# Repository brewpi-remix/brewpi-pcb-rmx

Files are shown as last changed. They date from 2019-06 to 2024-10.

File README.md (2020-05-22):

# BrewPi Remix Logo

*[@LBussy](https://github.com/lbussy)'s forks of the original [BrewPi Project](https://github.com/BrewPi)*.  This project has a new website, please also visit https://www.brewpiremix.com.  All files will remain here, the website is just to make it easier for me to keep current information available.

# BrewPi Remix Printed Circuit Board Eagle Files

This repository contains the Eagle files for printed circuit boards supporting [BrewPi Remix](https://www.brewpi.com/this-is-brewpi-0-2/).

## Boards Provided
Within this repository are:

- ESP8266 Boards (Supporting @Thorrak's [ESP8266 BrewPi Controllers](https://github.com/thorrak/brewpi-esp8266))
  - Wemos D1 breakout supporting BrewPi Remix or Fermentrack using @Thorrak's [ESP8266 firmware](https://github.com/thorrak/brewpi-esp8266)
  - RJ-45 breakout board, supporting ESP8266 controllers connected via straight-throgh RJ-45 (i,e, Ethernet) cables
- Arduino Uno shield supporting BrewPi Remix RevC as well as I2C
  - Rotary Encoder breakout to facilitate connecting a rotary encoder with DuPont wires
  - Breakout board, mostly for bench work, providing all possible connections via screw terminals as well as DuPont connections, plus heat/cool LED indicators

## Boards Manufacture
You may order boards for manufacture directly from these links:
- Arduino Shield [From PCBs.io](https://PCBs.io/share/zdeBw)
- Wemos D1 breakout [From PCBs.io](https://PCBs.io/share/z5JLZ)
- Breakout Board [From PCBs.io](https://PCBs.io/share/zvpLA)
- Rotary Encoder Breakout Board [From PCBs.io](https://PCBs.io/share/rJPlG)

## Modifying These Files
If you would like to personalize these board designs, you may modify them with [Autodesk's EAGLE](https://www.autodesk.com/products/eagle/overview). EAGLE is a scriptable electronic design automation (EDA) application with schematic capture, printed circuit board (PCB) layout, auto-router and computer-aided manufacturing (CAM) features. EAGLE stands for Easily Applicable Graphical Layout Editor and is developed by CadSoft Computer GmbH. The company was acquired by Autodesk Inc. in 2016.  

The program supports Windows, Linux, and Mac OS X.  EAGLE is available in a [free version](https://www.autodesk.com/products/eagle/free-download), as well as a [subscription-based version with more features](https://www.autodesk.com/products/eagle/compare).

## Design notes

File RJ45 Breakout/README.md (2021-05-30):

# BrewPi Remix Logo

Make or buy?  That is the question.  Since providing the below listed DIY breakout, I found these on Amazon (of course!):

- [Four-Way RJ45 Breakout Board](https://smile.amazon.com/Electronics-Salon-4-Way-Breakout-Terminal-Connector/dp/B01GNOBDPM)
- [RJ45 Ethernet Splitter (2-way)](https://smile.amazon.com/Splitter-Connectors-Ethernet-Interface-Internet/dp/B07CW7JHYV)
- [RJ45 Ethernet Splitter (3-way)](https://smile.amazon.com/Ethernet-Splitter-vienon-Adapter-Connector/dp/B0932B8JGJ)

I have the below setup in all my fermenters, but I have to say I might be tempted to use these if I had to do it again.

Note: These links are NOT affiliat elinks but are pointing to [smile.amazon.com](https://smile.amazon.com/gp/chpf/about/).  If you are not currently enrolled in this program, you should at least review the link.  It's an easy way to support your favorite charity every time you shop on Amazon.  If you are at a loss to pick a charity, may I suggest the [Wounded Warrior Project](https://www.woundedwarriorproject.org/)?

If you are interested in building a splitter, here's one way to go:

# RJ-45 Sensor Breakout

A breakout board created to connect sensors and the door switch via an RJ-45 straight-through cable (i.e. Ethernet.)

[Order from PCBs.io](#):

- 2 Layer Board - 0.7087 sq in (0.7038in x 1.0069in) / 457.22 sq/mm (17.88mm x 25.58mm)
- $2.83 per set of 4 ($4.00 per sq in)

| Top View | Bottom View |
| --- |:---:|
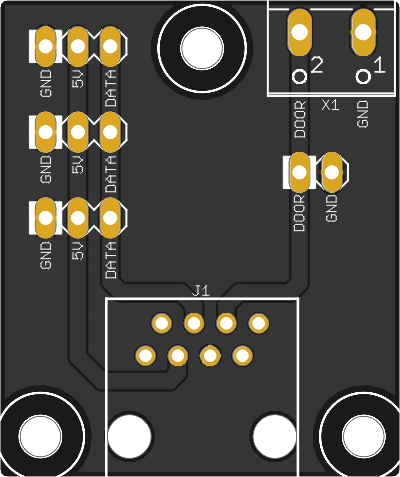
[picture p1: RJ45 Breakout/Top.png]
Board Top
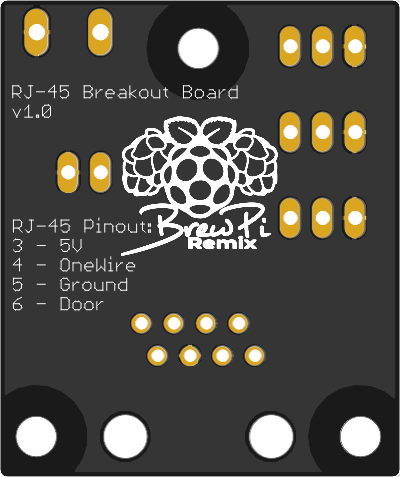
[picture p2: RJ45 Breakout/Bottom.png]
Board Bottom
|  |  |

[top]: Top.png "Board Top"
[bot]: Bottom.png "Board Bottom"

BOM:

- 1 x [PCB Breakout](#) (this project)
- 1 x [Wago 2-terminal Screw Clamp](https://www.aliexpress.com/item/32700056337.html) (X1)
- 3 x [Wago 3-terminal Screw Clamp](#) (X1)
- 1 x [RJ45 Modular Jack w/no shield](https://www.aliexpress.com/item/32736146888.html) (J1)

## Board Manufacture

You may order this board for manufacture directly from [PCBs.io](https://PCBs.io/share/rJPlG).

## 3D-Printed Case

See [this case](#) from Thorrak for a case you can print.

## Modifying These Files

If you would like to personalize these board designs, you may modify them with [Autodesk's EAGLE](https://www.autodesk.com/products/eagle/overview). EAGLE is a scriptable electronic design automation (EDA) application with schematic capture, printed circuit board (PCB) layout, auto-router and computer-aided manufacturing (CAM) features. EAGLE stands for Easily Applicable Graphical Layout Editor and is developed by CadSoft Computer GmbH. The company was acquired by Autodesk Inc. in 2016.  

The program supports Windows, Linux, and Mac OS X.  EAGLE is available in a [free version](https://www.autodesk.com/products/eagle/free-download), as well as a [subscription-based version with more features](https://www.autodesk.com/products/eagle/compare).

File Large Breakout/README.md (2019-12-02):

# BrewPi Remix Logo

# BrewPi Breakout v1.3.1a

Breakout Board for the [BrewPi Legacy Remix](https://www.brewpiremix.com) project. This optional breakout board is intended to be connected to the Arduino Shield v1.3.1a via a straight-through RJ45 terminated cable (i.e. an Ethernet cable.)  It allows the Arduino to be located remotely from the fermentation chamber.

[Order from PCBs.io](https://PCBs.io/share/zvpLA):

- 2 Layer Board - 2.3751 sq in (1.2130in x 1.9580in) / 1532.32 sq/mm (30.81mm x 49.73mm)
- $9.38 per set of 4 ($3.95 per sq in)

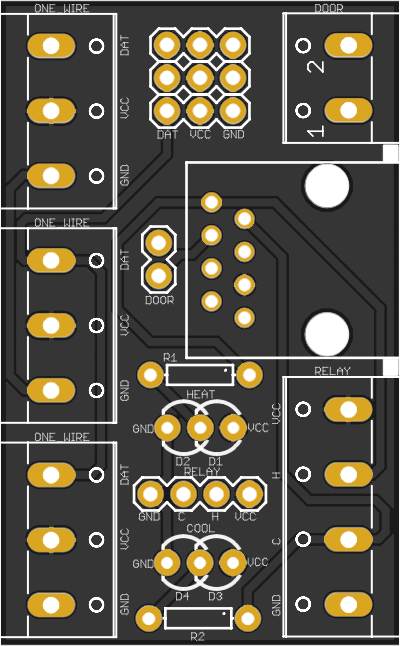
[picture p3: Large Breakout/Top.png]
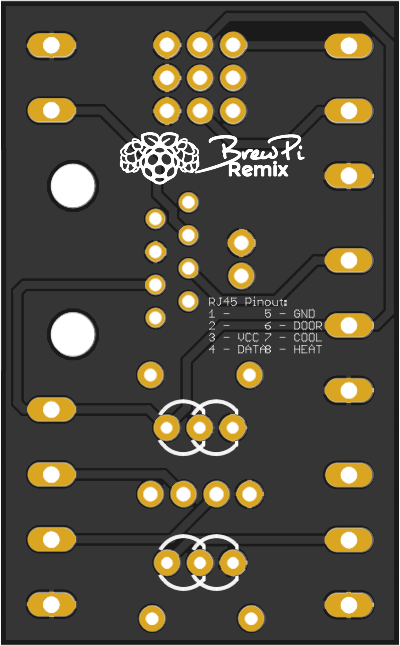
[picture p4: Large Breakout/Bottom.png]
 

## Supported Features:

  * Door switch
  * Heat/Cool
    * Dupont pins
    * Screw terminal
  * Heat/Cool LEDs
  * Temp Sensors
    * Three Dupont pin sets
    * Three screw terminals

## Usage Notes:
Since this board is intended to support multiple configurations, some customization during assembly is required.

  - Heat / Cool LEDs - You will use different connections for LEDs depending on the configuration of your actuators.  Connections are provided for two LEDs each for heat and cool, however you will only use one based on your setup
    - Inverted (typical for relay board) - Connect the LED between VCC and the center pin.  A resistor is not needed as there is one on the board
    - Non-Inverted (typical for SSRs) - Connect the LED between the center pin and GND.  A resistor is not needed as there is one on the board

## BOM:

  * 1 ea [Red 3mm LED](https://www.mouser.com/ProductDetail/638-MV5064.MP4B)
  * 1 ea [Blue 3mm LED](https://www.mouser.com/ProductDetail/941-C503BBCNCV0Z0461)
  * 2 ea [220Ω 1/4W Axial Resistors](https://www.mouser.com/ProductDetail/660-MF1-4DCT52R2200F)
  * 1 ea 4-Pin header
  * 1 ea 2-Pin header
  * 3 ea 3-Pin headers
  * 1 ea RJ45 terminal
  * 3 ea 3-Position screw terminal
  * 1 ea 4-Position screw terminal
  * 1 ea 2-Position screw terminal

## Board Manufacture
You may order this board for manufacture directly from [PCBs.io](https://PCBs.io/share/zvpLA).

## Modifying These Files
If you would like to personalize these board designs, you may modify them with [Autodesk's EAGLE](https://www.autodesk.com/products/eagle/overview). EAGLE is a scriptable electronic design automation (EDA) application with schematic capture, printed circuit board (PCB) layout, auto-router and computer-aided manufacturing (CAM) features. EAGLE stands for Easily Applicable Graphical Layout Editor and is developed by CadSoft Computer GmbH. The company was acquired by Autodesk Inc. in 2016.  

The program supports Windows, Linux, and Mac OS X.  EAGLE is available in a [free version](https://www.autodesk.com/products/eagle/free-download), as well as a [subscription-based version with more features](https://www.autodesk.com/products/eagle/compare).

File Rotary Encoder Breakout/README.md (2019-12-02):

# BrewPi Remix Logo

# Rotary Encoder Breakout v1.0

A breakout board to provide pins for connecting the rotary encoder to the BrewPi controller.  Designed for CUI, [ACZ11BR1E-15FD1-20C](https://www.mouser.com/ProductDetail/490-CZ11BR1E15FD120C) or similar footprint.  Despite the picture linked on that page, you want a vertical mounting encoder (and that one really is.)  You don't really *need* this, but it will surely make it easier to connect things with Dupont wires.

[Order from PCBs.io](https://PCBs.io/share/rJPlG):

- 2 Layer Board - 0.7087 sq in (0.7038in x 1.0069in) / 457.22 sq/mm (17.88mm x 25.58mm)
- $2.83 per set of 4 ($4.00 per sq in)

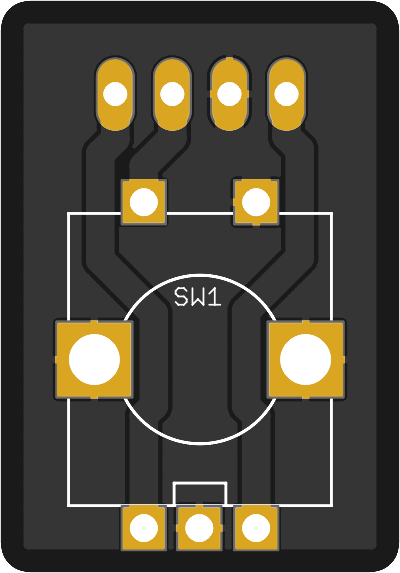
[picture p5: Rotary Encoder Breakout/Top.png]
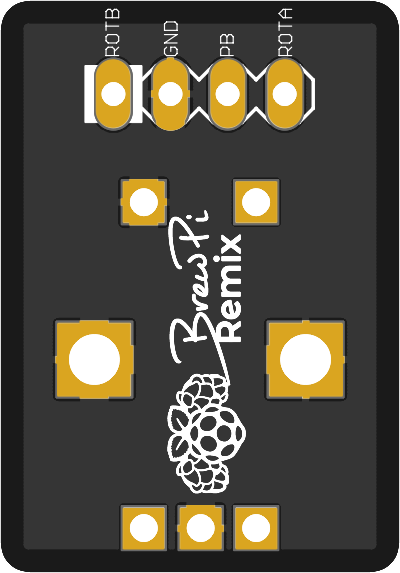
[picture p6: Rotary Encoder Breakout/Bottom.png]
 

## BOM:

- 1 each [PCB](https://PCBs.io/share/rJPlG) (this project)
- 1 each [Four-pin 2.54mm Dupont header](https://www.mouser.com/ProductDetail/3M-Electronic-Solutions-Division/2306-6111-TG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), male or female according to your preference
- 1 each CUI [Rotary Encoder ACZ11BR1E-15FD1-20C](https://www.mouser.com/ProductDetail/490-CZ11BR1E15FD120C)  You want a magnetic encoder with a vertical shaft, no pull-ups, and 20 detents
- 1 each [Rotary Knob](https://www.mouser.com/ProductDetail/450-4763)

## Board Manufacture

You may order this board for manufacture directly from [PCBs.io](https://PCBs.io/share/rJPlG).

## Modifying These Files

If you would like to personalize these board designs, you may modify them with [Autodesk's EAGLE](https://www.autodesk.com/products/eagle/overview). EAGLE is a scriptable electronic design automation (EDA) application with schematic capture, printed circuit board (PCB) layout, auto-router and computer-aided manufacturing (CAM) features. EAGLE stands for Easily Applicable Graphical Layout Editor and is developed by CadSoft Computer GmbH. The company was acquired by Autodesk Inc. in 2016.  

The program supports Windows, Linux, and Mac OS X.  EAGLE is available in a [free version](https://www.autodesk.com/products/eagle/free-download), as well as a [subscription-based version with more features](https://www.autodesk.com/products/eagle/compare).

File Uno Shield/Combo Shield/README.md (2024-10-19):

# BrewPi Remix Logo

# BrewPi Arduino Uno Shield v1.3.1a (I2C/Parallel LCD)

Arduino Uno shield for the [BrewPi Remix](https://www.brewpiremix.com) project. This is an new board design which incorporates an I2C LCD header in addition to the original parallel LCD header on the RevC.  The I2C display is supported in version 0.5.3 of BrewPi Legacy Remix Scripts, WWW and Tools, coupled with version 0.2.12 of the Arduino Firmware.

[Order from PCBs.io]():  (I removed this link because PCBs.io appear to have been overtaken by malware.  [OshPark](https://oshpark.com/) is a good choice for smaller quantities.)

- 2 Layer Board - 5.1164 sq in (2.1200in x 2.4134in) / 3300.9 sq/mm (53.85mm x 61.3mm)
- $19.39 per set of 4 ($3.79 per sq in)

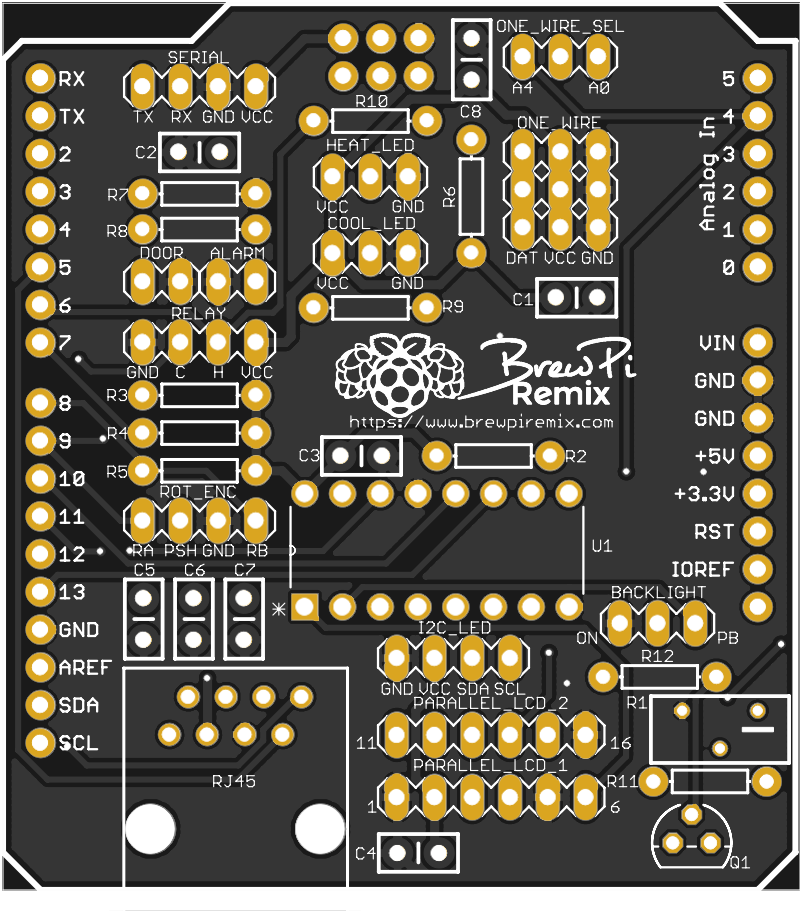
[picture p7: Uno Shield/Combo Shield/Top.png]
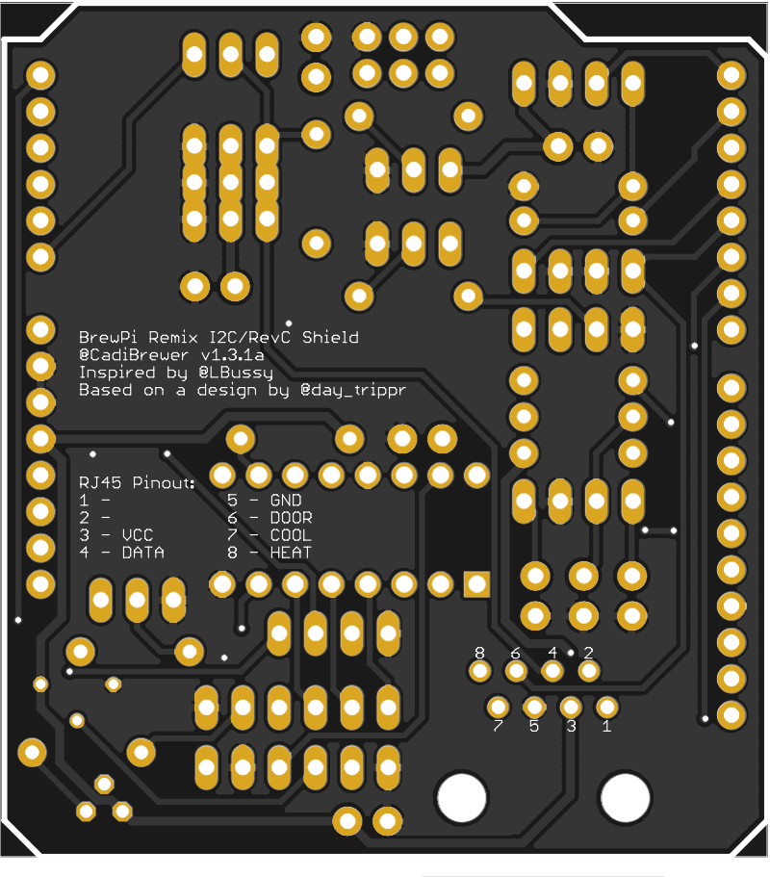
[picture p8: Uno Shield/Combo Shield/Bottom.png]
 

## Supported Features:

  * Wireless to Serial Bridge (Bluetooth or ESP8266 module)
  * Door switch
  * Alarm
  * Heat/Cool Relay
  * Rotary Encoder w/Pushbutton
  * Heat/Cool LEDs
  * OneWire Selector A0/A4 (required for I2C)
  * Three OneWire connections
  * I2C LCD; or;
  * Parallel LCD
  * RJ45 connector includes support for:
    * OneWire
    * Door Switch
    * Heat/Cool Relay
  * All Arduino headers available

## Usage Notes:
Since this board is intended to support both the RevC as well as the I2C firmware, some configuration is required via jumper caps.

  - ONE_WIRE_SEL Jumper - If you do not select the proper configuration, you may not be able to configure the OneWire sensors, the display may fault, or both.
    - Jump between A4 and the center pin for RevC
    - Jump between A0 and the center pin for I2C
  - Backlight Timeout - If you do not have a rotary encoder you will not be able to wake the backlight if it times out.  You can configure the board to never turn off the backlight
    - RevC - The BACKLIGHT jumper has two settings:
      - Jump between ON and the center pin to have the backlight stay on
      - Jump between PB and the center pin to have the backlight time out
    - I2C - The backlight setting uses the rotary encoder header
      - If you have a rotary encoder, pushing the button during a controller reset will disable backlight timer
      - If you do not have a rotary encoder, adding a jumper on the ROT_ENC header between PSH and GND will disable backlight timer
  - Heat / Cool LEDs - You will use different connections for LEDs depending on the configuration of your actuators
    - Inverted (typical for relay board) - Connect the LED between VCC and the center pin.  A resistor is not needed as there is one on the board
    - Non-Inverted (typical for SSRs) - Connect the LED between the center pin and GND.  A resistor is not needed as there is one on the board

## BOM:

  * From Mouser (by using [this link](https://www.mouser.com/ProjectManager/ProjectDetail.aspx?AccessID=d74098d8b5) you can view all of these parts on Mouser and simply click the "Order Project" button):
    * 7 ea [0.1μF Ceramic Capacitor](https://www.mouser.com/ProductDetail/?qs=PmkNt%2FFLxQc4kNUCHU6a6Q%3D%3D) (C1-7)
    * 1 ea [1.0μF Ceramic Capacitor](https://www.mouser.com/ProductDetail/?qs=AQlKX63v8RtdX%2FUKFBhcig%3D%3D) (C8)
    * 1 ea [10kΩ Trimmer Resistor](https://www.mouser.com/ProductDetail/?qs=V3Em1enZyNPGF2%252BnCaKTKw%3D%3D) (R1)
    * 4 ea [10kΩ Axial Resistor 1/4W](https://www.mouser.com/ProductDetail/?qs=AtFvwFU%2F1FmCMXRebRRiVA%3D%3D) (R3-5, 12)
    * 1 ea [150Ω Axial Resistor 1/4W](https://www.mouser.com/ProductDetail/?qs=7jyBjEprRBipjkz1NPmruA%3D%3D) (R11)
    * 1 ea [1kΩ Axial Resistor 1/4W](https://www.mouser.com/ProductDetail/?qs=ddCg%252BR5cWn2sqOoxwN8P1g%3D%3D) (R8)
    * 1 ea [20kΩ Axial Resistor 1/4W](https://www.mouser.com/ProductDetail/KOA-Speer/MF1-4CC2002F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) (R2)
    * 2 ea [220Ω Axial Resistor 1/4W](https://www.mouser.com/ProductDetail/?qs=KVzGhl%2FcVV1aGF8Vc%2F%252BvDg%3D%3D) (R9, 10)
    * 1 ea [2kΩ Axial Resistor 1/4W](https://www.mouser.com/ProductDetail/?qs=iPPgFPFs9PM72iUDc08rBg%3D%3D) (R7)
    * 1 ea [4.7kΩ Axial Resistor 1/4W](https://www.mouser.com/ProductDetail/?qs=WbbykRgge7o4TK6QsdXS5A%3D%3D) (R6)
    * 1 ea [2N3906 PNP Transistor](https://www.mouser.com/ProductDetail/?qs=iN0KuJO79Kbn9o7a2lB4uA%3D%3D) (Q1)
    * 1 ea [SN74HC595N 8-Bit Shift Register](https://www.mouser.com/ProductDetail/?qs=IEl3ej0IqwBTHkYa8XPoMQ%3D%3D) (U1)
    * 1 ea [16-pin IC Socket](https://www.mouser.com/ProductDetail/?qs=5aG0NVq1C4zi9nx%252BGroISQ%3D%3D) (U1)
  * From Adafruit:
    * [Shield stacking headers for Arduino](https://www.adafruit.com/product/85)
    * [Break-away 0.1" 36-pin strip male header - Black - 10 pack](https://www.adafruit.com/product/392), more than enough for:
      * 2 ea 2-pin Header 2.54mm pitch (or 1 ea 4 pin)
      * 7 ea 3-pin Header 2.54mm pitch
      * 4 ea 4-pin Header 2.54mm pitch
      * 2 ea 6-pin Header 2.54mm pitch
  * 2 ea [Jumper Cap](https://www.amazon.com/ZYAMY-2-54mm-Standard-Circuit-Connection/dp/B077957RN7) (or you can use a female/female Dupont jumpers but caps are definitely better looking)
  * 1 ea [RJ45 Socket](https://www.aliexpress.com/item/High-Quality-20pcs-RJ45-8P8C-Computer-Internet-Network-PCB-Jack-Socket-Black/32736146888.html)

Other items you may want in order to complete your project:

  * LCD Display, either;
    * [20x4 LCD Parallel](https://www.amazon.com/SunFounder-Serial-Module-Arduino-Mega2560/dp/B071W8SW9R), or;
    * [20x4 LCD I2C](https://www.amazon.com/SunFounder-Serial-Module-Arduino-Mega2560/dp/B01GPUMP9C)
  * [5v 2-Channel Relay Module](https://www.amazon.com/gp/product/B00TMFVVG6)
  * [Rotary Encoder](https://www.mouser.com/ProductDetail/490-CZ11BR1E15FD120C)  - You want a magnetic encoder, no pull-ups, and 20 detents
  * [Knob for Rotary Encoder](https://www.mouser.com/ProductDetail/Eagle-Plastic-Devices/450-4763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)
  * [Rotary Encoder Breakout Board](https://PCBs.io/share/zkPZ0)
  * At least two [DS18B20 Waterproof Temperature Sensors](https://www.amazon.com/gp/product/B01JKVRVNI)
  * Assorted [Dupont Jumper Wires](https://www.amazon.com/Multicolored-Breadboard-Dupont-Jumper-Wires/dp/B073X7P6N2) (male-male, male-female, female-female)

## Board Manufacture

You may order this board for manufacture directly from [pcbs.io](https://PCBs.io/share/zdeBw).

## 3D-Printed Case

See [this case](https://www.thingiverse.com/thing:3416312) from @gromitdj for a case you can print.

## Modifying These Files
If you would like to personalize these board designs, you may modify them with [Autodesk's EAGLE](https://www.autodesk.com/products/eagle/overview). EAGLE is a scriptable electronic design automation (EDA) application with schematic capture, printed circuit board (PCB) layout, auto-router and computer-aided manufacturing (CAM) features. EAGLE stands for Easily Applicable Graphical Layout Editor and is developed by CadSoft Computer GmbH. The company was acquired by Autodesk Inc. in 2016.  

The program supports Windows, Linux, and Mac OS X.  EAGLE is available in a [free version](https://www.autodesk.com/products/eagle/free-download), as well as a [subscription-based version with more features](https://www.autodesk.com/products/eagle/compare).

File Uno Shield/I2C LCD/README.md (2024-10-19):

# I2C Uno Shield

The design here is specific to the I2C variant only of the BrewPi firmware.

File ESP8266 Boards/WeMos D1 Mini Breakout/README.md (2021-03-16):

# BrewPi Remix Logo

# Wemos D1 Mini BrewPi Breakout

A Wemos D1 Mini breakout board for BrewPi-derivative ESP8266 projects. No third-party level shifter is required.  Through-hole components only for ease of assembly.

[Order from OshPark](https://oshpark.com/shared_projects/YLXZEzde):

- 2 layer board of 1.74 x 1.74 inches (44.2 x 44.1 mm) 
- $15.10 per set of 3

| Top View | Bottom View |
| --- |:---:|
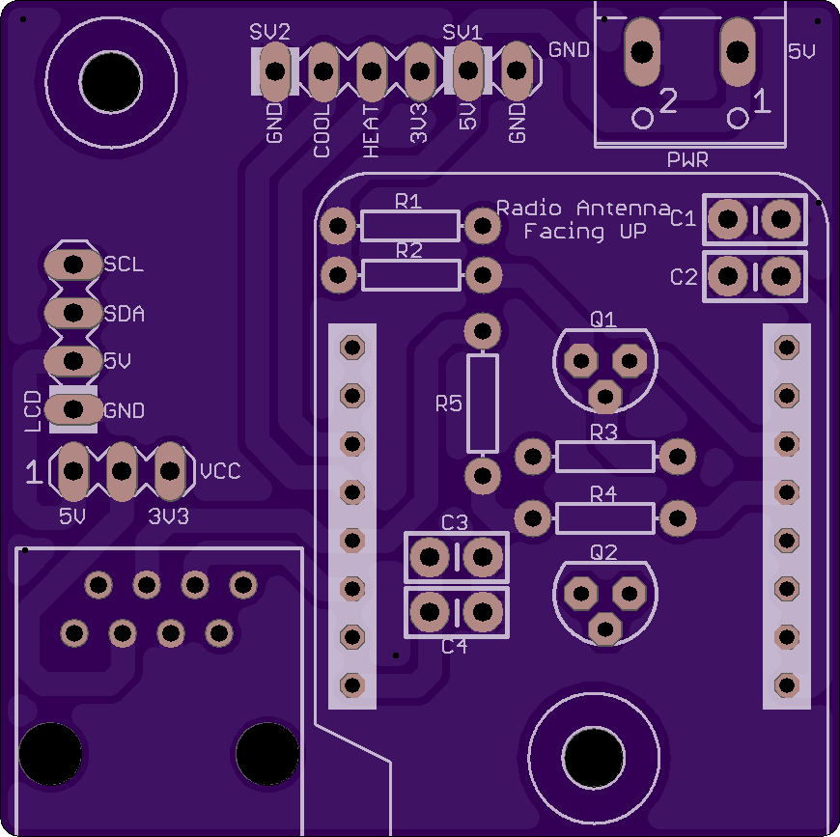
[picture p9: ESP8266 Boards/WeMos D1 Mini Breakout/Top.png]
Board Top
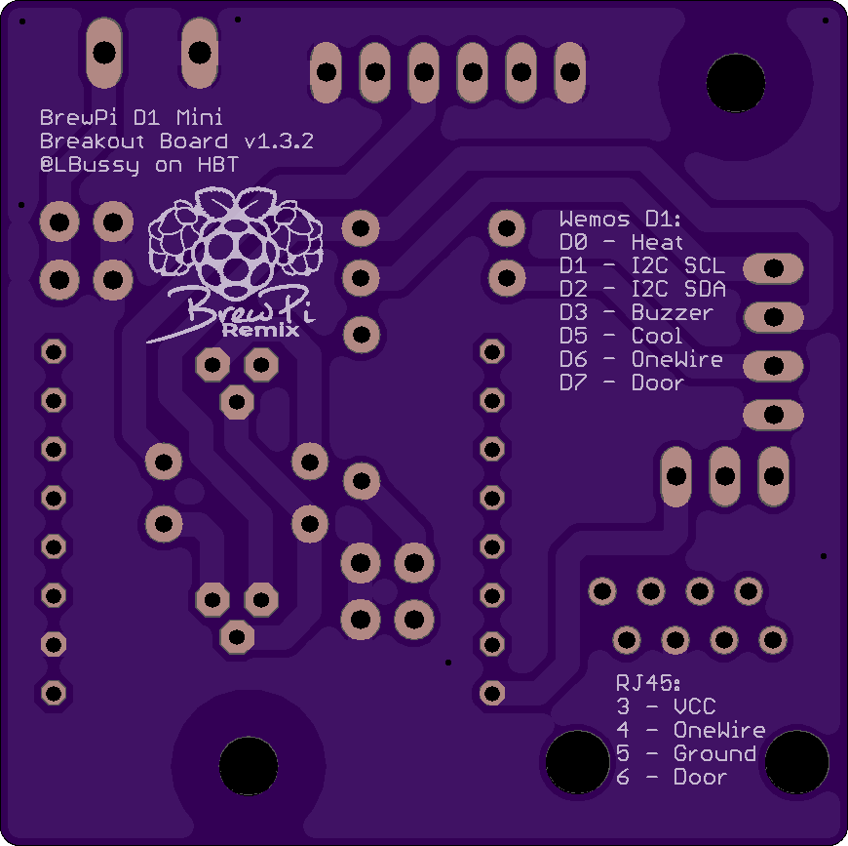
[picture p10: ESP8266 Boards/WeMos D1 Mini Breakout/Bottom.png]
Board Bottom
|  |  |

[top]: Top.png "Board Top"
[bot]: Bottom.png "Board Bottom"

## BOM (controller/shield only):

- 1 x [PCB Shield](https://oshpark.com/shared_projects/YLXZEzde) (this project)
- 1 x [Wemos D1 Mini](https://www.aliexpress.com/item/32688079351.html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,searchweb201602_1,searchweb201603_52_) (U1)
- 2 x Male 8-pin header (comes with controller)
- 2 x Female 8-pin header (comes with controller)
- 2 x [1.0uF Capacitor](https://www.mouser.com/ProductDetail/KEMET/C320C105K5R5TA?qs=sGAEpiMZZMt3KoXD5rJ2N0CWo9MbFM%2FuWljjm75KZzs%3D) (C1, C3)
- 2 x [0.1uF Capacitor](https://www.mouser.com/ProductDetail/KEMET/C320C104K3R5TA?qs=sGAEpiMZZMt3KoXD5rJ2N4ZXb0dQpKOeXkTyt%2FbcGss%3D) (C2, C4)
- 2 x [2N7000 N-Channel MOSFET](https://www.mouser.com/ProductDetail/ON-Semiconductor/2N7000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) (Q1, Q2)
- 5 x [10kΩ 1/4-Watt Resistor](https://www.mouser.com/ProductDetail/KOA-Speer/CF1-4CT52R103J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) (R1-R4)
- 1 x [2.2kΩ 1/4-Watt Resistor](https://www.mouser.com/ProductDetail/KOA-Speer/CF1-4CT52R222J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) (R5)
- 1 x [Wago 2-terminal Screw Clamp](https://www.aliexpress.com/item/32700056337.html) (PWR)
- 1 x [RJ45 Modular Jack w/no shield](https://www.aliexpress.com/item/32736146888.html) (J1)
- 2 x [4-pin DuPont Header](https://www.aliexpress.com/item/32670112443.html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,searchweb201602_1,searchweb201603_52) (RELAY, LCD)
- 1 x [3-pin DuPont Header](https://www.aliexpress.com/item/32670112443.html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,searchweb201602_1,searchweb201603_52) (PWR)
- 1 x [2-pin DuPont Header](https://www.aliexpress.com/item/32670112443.html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,searchweb201602_1,searchweb201603_52) (PWR)

## Board Manufacture

You may order this board for manufacture directly from [PCBs.io](https://PCBs.io/share/z5JLZ).

## 3D-Printed Case

See [this case](https://www.thingiverse.com/thing:2874176) from Thorrak for a case you can print.

## Modifying These Files

If you would like to personalize these board designs, you may modify them with [Autodesk's EAGLE](https://www.autodesk.com/products/eagle/overview). EAGLE is a scriptable electronic design automation (EDA) application with schematic capture, printed circuit board (PCB) layout, auto-router and computer-aided manufacturing (CAM) features. EAGLE stands for Easily Applicable Graphical Layout Editor and is developed by CadSoft Computer GmbH. The company was acquired by Autodesk Inc. in 2016.  

The program supports Windows, Linux, and Mac OS X.  EAGLE is available in a [free version](https://www.autodesk.com/products/eagle/free-download), as well as a [subscription-based version with more features](https://www.autodesk.com/products/eagle/compare).

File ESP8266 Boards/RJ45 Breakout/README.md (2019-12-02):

# BrewPi Remix Logo

# RJ-45 Sensor Breakout

A breakout board created to connect sensors and the door switch via an RJ-45 straight-through cable (i.e. Ethernet.)

[Order from PCBs.io](https://PCBs.io/share/8ngBx):

- 2 Layer Board - 0.7087 sq in (0.7038in x 1.0069in) / 457.22 sq/mm (17.88mm x 25.58mm)
- $2.83 per set of 4 ($4.00 per sq in)

| Top View | Bottom View |
| --- |:---:|
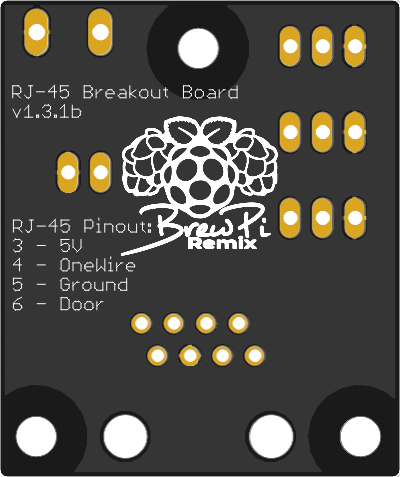
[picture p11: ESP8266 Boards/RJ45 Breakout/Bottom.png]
Board Bottom
| Board Top |  |

[top]: Top.png "Board Top"
[bot]: Bottom.png "Board Bottom"

BOM:

- 1 x [PCB Breakout](https://PCBs.io/share/8ngBx) (this project)
- 1 x [Wago 2-terminal Screw Clamp](https://www.aliexpress.com/item/32700056337.html) (X1)
- 1 x [RJ45 Modular Jack w/no shield](https://www.aliexpress.com/item/32736146888.html) (J1)
- 3 x [3-pin DuPont Header](https://www.aliexpress.com/item/32670112443.html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,searchweb201602_1,searchweb201603_52) (JP1-3)
- 1 x [2-pin DuPont Header](https://www.aliexpress.com/item/32670112443.html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,searchweb201602_1,searchweb201603_52) (JP4)

## Board Manufacture

You may order this board for manufacture directly from [PCBs.io](https://PCBs.io/share/rJPlG).

## 3D-Printed Case

See [this case](https://www.thingiverse.com/thing:2954861) from Thorrak for a case you can print.

## Modifying These Files

If you would like to personalize these board designs, you may modify them with [Autodesk's EAGLE](https://www.autodesk.com/products/eagle/overview). EAGLE is a scriptable electronic design automation (EDA) application with schematic capture, printed circuit board (PCB) layout, auto-router and computer-aided manufacturing (CAM) features. EAGLE stands for Easily Applicable Graphical Layout Editor and is developed by CadSoft Computer GmbH. The company was acquired by Autodesk Inc. in 2016.  

The program supports Windows, Linux, and Mac OS X.  EAGLE is available in a [free version](https://www.autodesk.com/products/eagle/free-download), as well as a [subscription-based version with more features](https://www.autodesk.com/products/eagle/compare).

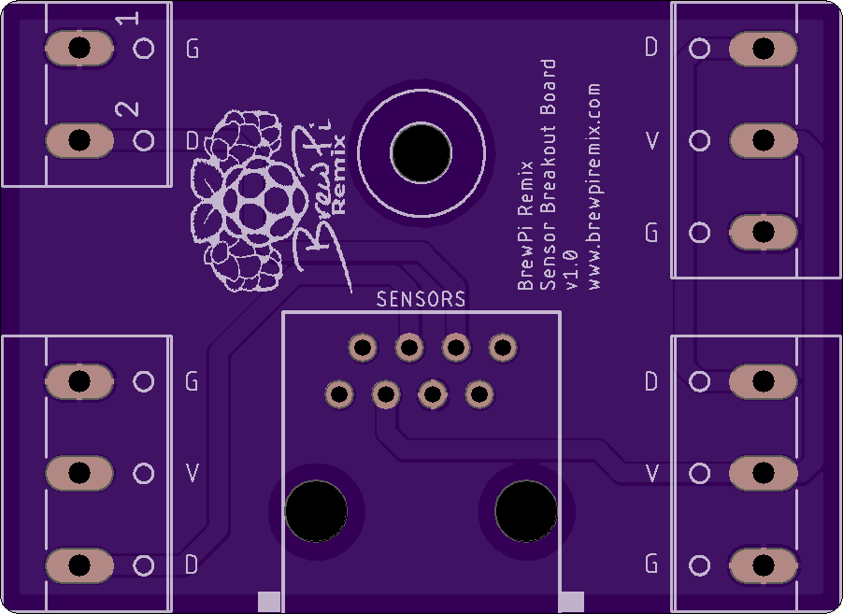
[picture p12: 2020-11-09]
RJ45 Breakout/RJ45 Breakout - Top.png

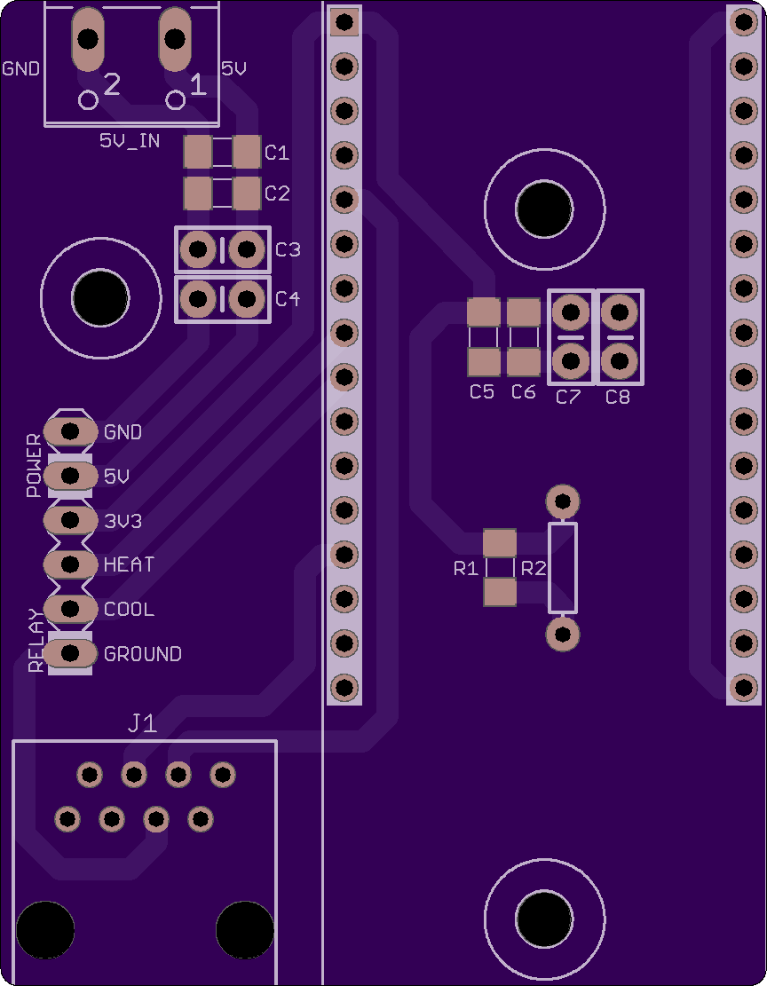
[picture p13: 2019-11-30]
D32 Pro Breakout - TFT Touch/Top.png

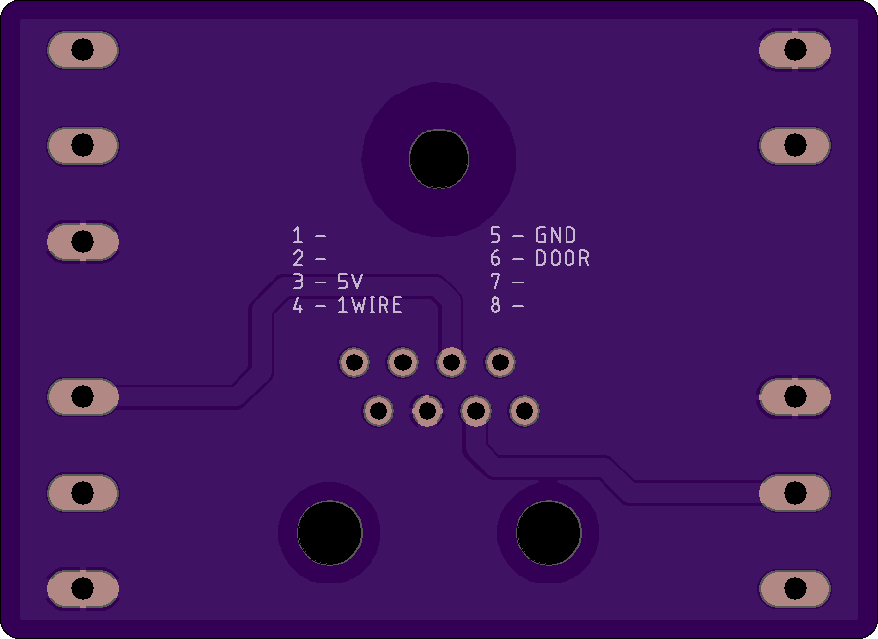
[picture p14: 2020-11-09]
RJ45 Breakout/RJ45 Breakout - Bottom.png

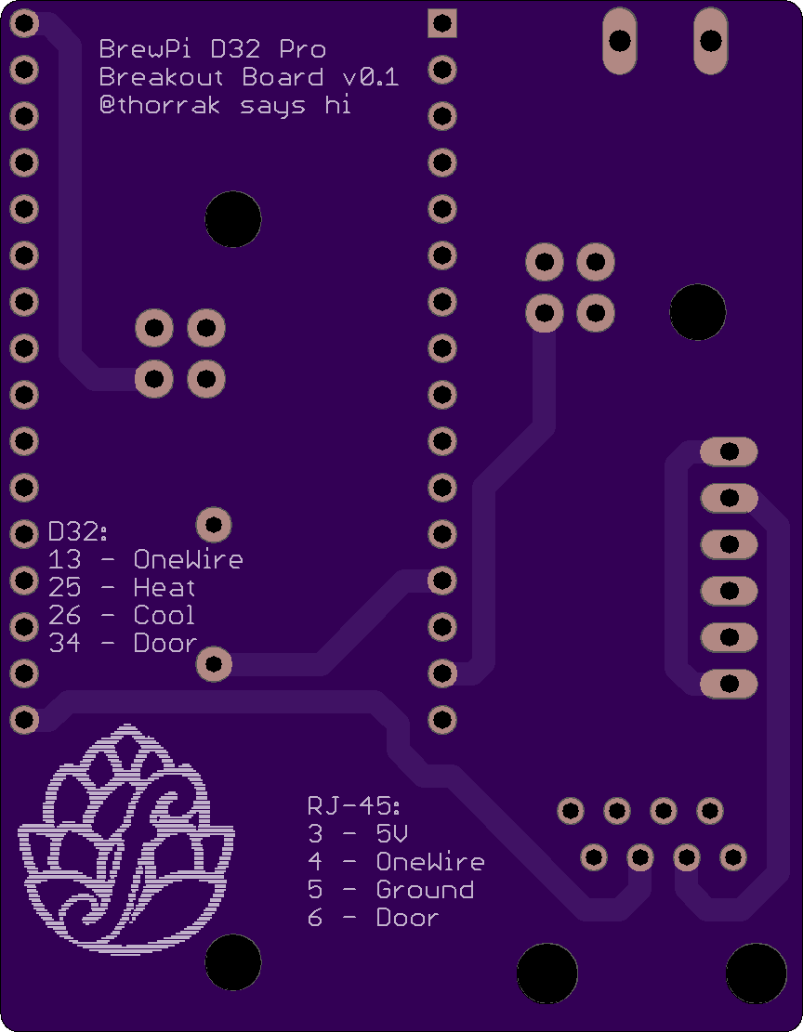
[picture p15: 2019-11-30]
D32 Pro Breakout - TFT Touch/Bottom.png

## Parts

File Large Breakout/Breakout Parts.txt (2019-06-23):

Partlist exported from C:/Users/lee/OneDrive/Desktop/BrewPi/Git/brewpi-pcb-rmx/large_breakout/Breakout.sch at 6/23/2019 3:37 PM

Part       Value   Device            Package        Description                                                                                                     MF MPN     OC_FARNELL OC_NEWARK PROD_ID    VALUE        
D1         HINV    LED3MM            LED_3MM        LED (Generic)                                                                                                                                   DIO-08794               
D2         HNON    LED3MM            LED_3MM        LED (Generic)                                                                                                                                   DIO-08794               
D3         CINV    LED3MM            LED_3MM        LED (Generic)                                                                                                                                   DIO-08794               
D4         CNON    LED3MM            LED_3MM        LED (Generic)                                                                                                                                   DIO-08794               
DOOR       2-PIN   CONN_02           1X02           Multi connection point. Often used as Generic Header-pin footprint for 0.1 inch spaced/style header connections                                                         
ONE_WIRE1  3-PIN   CONN_03           1X03           Multi connection point. Often used as Generic Header-pin footprint for 0.1 inch spaced/style header connections                                 XXX-00000  455-1750-1-ND
ONE_WIRE2  3-PIN   CONN_03           1X03           Multi connection point. Often used as Generic Header-pin footprint for 0.1 inch spaced/style header connections                                 XXX-00000  455-1750-1-ND
ONE_WIRE3  3-PIN   CONN_03           1X03           Multi connection point. Often used as Generic Header-pin footprint for 0.1 inch spaced/style header connections                                 XXX-00000  455-1750-1-ND
R1         220Ω    RESISTORAXIAL-0.3 AXIAL-0.3      Resistor                                                                                                                                                                
R2         220Ω    RESISTORAXIAL-0.3 AXIAL-0.3      Resistor                                                                                                                                                                
RELAY      4-PIN   CONN_04PTH        1X04           Multi connection point. Often used as Generic Header-pin footprint for 0.1 inch spaced/style header connections                                 CONN-09696              
RELAY_TERM 4TERM   W237-4            W237-4         WAGO SCREW CLAMP                                                                                                           unknown    unknown                           
X1         RJ45-8X RJ45-8X           RJ45-NO-SHIELD CORCOM Modular RJ Jacks No Shield                                                                                  RJ45-8X unknown    16R6101                           
X2         4TERM   W237-102          W237-102       WAGO SCREW CLAMP                                                                                                   237-102 unknown    70K9898                           
X3         3TERM   W237-103          W237-103       WAGO SCREW CLAMP                                                                                                   237-103 unknown    18M7116                           
X4         3TERM   W237-103          W237-103       WAGO SCREW CLAMP                                                                                                   237-103 unknown    18M7116                           
X5         3TERM   W237-103          W237-103       WAGO SCREW CLAMP                                                                                                   237-103 unknown    18M7116

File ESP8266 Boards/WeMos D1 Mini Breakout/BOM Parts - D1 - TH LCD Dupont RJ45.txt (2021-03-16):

Partlist exported from C:/Users/lee/OneDrive/Documents/GitHub/brewpi-pcb-rmx/ESP8266 Boards/WeMos D1 Mini Breakout/D1 - TH LCD Dupont RJ45.sch at 3/16/2021 7:01 AM

Part   Value       Device               Package               Description                       MF MPN     OC_FARNELL OC_NEWARK POPULARITY PROD_ID   VALUE
C1     1.0μF       CAP_CERAMIC_2.54     CAP_PTH-2.54                                                                                                      
C2     0.1μF       CAP_CERAMIC_2.54     CAP_PTH-2.54                                                                                                      
C3     1.0μF       CAP_CERAMIC_2.54     CAP_PTH-2.54                                                                                                      
C4     0.1μF       CAP_CERAMIC_2.54     CAP_PTH-2.54                                                                                                      
J1     RJ45-8X     RJ45-8X              RJ45-NO-SHIELD-NOLINE CORCOM Modular RJ Jacks No Shield    RJ45-8X unknown    16R6101                             
LCD    4-PIN       HDR-4                HDR-4_VERT            PIN HEADER                                                                                  
POWER  PWR         W237-102             W237-102              WAGO SCREW CLAMP                     237-102 unknown    70K9898                             
Q1     2N7000      2N7000               TO-92                                                                                                             
Q2     2N7000      2N7000               TO-92                                                                                                             
R1     10k         10KOHM-HORIZ-1/4W-1% AXIAL-0.3             10kΩ resistor                                                                RES-12183 10k  
R2     10k         10KOHM-HORIZ-1/4W-1% AXIAL-0.3             10kΩ resistor                                                                RES-12183 10k  
R3     10k         10KOHM-HORIZ-1/4W-1% AXIAL-0.3             10kΩ resistor                                                                RES-12183 10k  
R4     10k         10KOHM-HORIZ-1/4W-1% AXIAL-0.3             10kΩ resistor                                                                RES-12183 10k  
R5     2.2k        10KOHM-HORIZ-1/4W-1% AXIAL-0.3             10kΩ resistor                                                                RES-12183 10k  
RELAY  4-PIN       HDR-4                HDR-4_VERT            PIN HEADER                                                                                  
RPOWER 2-PIN       HDR-2                HDR-2_VERT                                                                                                        
U$1    WEMOSNOTEXT WEMOSNOTEXT          WEMOS_D1-NOTEXT                                                                                                   
VCC    3-PIN       MA03-1               MA03-1                PIN HEADER                                   unknown    unknown   48

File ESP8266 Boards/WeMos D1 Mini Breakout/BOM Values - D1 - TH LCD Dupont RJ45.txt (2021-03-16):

Partlist exported from C:/Users/lee/OneDrive/Documents/GitHub/brewpi-pcb-rmx/ESP8266 Boards/WeMos D1 Mini Breakout/D1 - TH LCD Dupont RJ45.sch at 3/16/2021 7:02 AM

Qty Value       Device               Package               Parts          Description                       MF MPN     OC_FARNELL OC_NEWARK POPULARITY PROD_ID   VALUE
2   0.1μF       CAP_CERAMIC_2.54     CAP_PTH-2.54          C2, C4                                                                                                     
2   1.0μF       CAP_CERAMIC_2.54     CAP_PTH-2.54          C1, C3                                                                                                     
4   10k         10KOHM-HORIZ-1/4W-1% AXIAL-0.3             R1, R2, R3, R4 10kΩ resistor                                                                RES-12183 10k  
1   2-PIN       HDR-2                HDR-2_VERT            RPOWER                                                                                                     
1   2.2k        10KOHM-HORIZ-1/4W-1% AXIAL-0.3             R5             10kΩ resistor                                                                RES-12183 10k  
2   2N7000      2N7000               TO-92                 Q1, Q2                                                                                                     
1   3-PIN       MA03-1               MA03-1                VCC            PIN HEADER                                   unknown    unknown   48                        
2   4-PIN       HDR-4                HDR-4_VERT            LCD, RELAY     PIN HEADER                                                                                  
1   PWR         W237-102             W237-102              POWER          WAGO SCREW CLAMP                     237-102 unknown    70K9898                             
1   RJ45-8X     RJ45-8X              RJ45-NO-SHIELD-NOLINE J1             CORCOM Modular RJ Jacks No Shield    RJ45-8X unknown    16R6101                             
1   WEMOSNOTEXT WEMOSNOTEXT          WEMOS_D1-NOTEXT       U$1

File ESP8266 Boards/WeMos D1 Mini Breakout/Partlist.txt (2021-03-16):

Partlist

Exported from D1 - TH LCD Dupont RJ45.sch at 3/16/2021 7:05 AM

EAGLE Version 9.6.2 Copyright (c) 1988-2020 Autodesk, Inc.

Assembly variant: 

Part     Value          Device               Package               Library             Sheet

C1       1.0?F          CAP_CERAMIC_2.54     CAP_PTH-2.54          Donnie              1
C2       0.1?F          CAP_CERAMIC_2.54     CAP_PTH-2.54          Donnie              1
C3       1.0?F          CAP_CERAMIC_2.54     CAP_PTH-2.54          Donnie              1
C4       0.1?F          CAP_CERAMIC_2.54     CAP_PTH-2.54          Donnie              1
J1       RJ45-8X        RJ45-8X              RJ45-NO-SHIELD-NOLINE con-tycoelectronics 1
LCD      4-PIN          HDR-4                HDR-4_VERT            Donnie              1
POWER    PWR            W237-102             W237-102              con-wago-500        1
Q1       2N7000         2N7000               TO-92                 Donnie              1
Q2       2N7000         2N7000               TO-92                 Donnie              1
R1       10k            10KOHM-HORIZ-1/4W-1% AXIAL-0.3             SparkFun-Resistors  1
R2       10k            10KOHM-HORIZ-1/4W-1% AXIAL-0.3             SparkFun-Resistors  1
R3       10k            10KOHM-HORIZ-1/4W-1% AXIAL-0.3             SparkFun-Resistors  1
R4       10k            10KOHM-HORIZ-1/4W-1% AXIAL-0.3             SparkFun-Resistors  1
R5       2.2k           10KOHM-HORIZ-1/4W-1% AXIAL-0.3             SparkFun-Resistors  1
RELAY    4-PIN          HDR-4                HDR-4_VERT            Donnie              1
RPOWER   2-PIN          HDR-2                HDR-2_VERT            Donnie              1
U$1      WEMOSNOTEXT    WEMOSNOTEXT          WEMOS_D1-NOTEXT       Wemos               1
VCC      3-PIN          MA03-1               MA03-1                con-lstb            1

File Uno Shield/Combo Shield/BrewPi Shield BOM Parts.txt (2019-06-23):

Partlist exported from C:/Users/lee/OneDrive/Desktop/BrewPi/Git/brewpi-pcb-rmx/shield/BrewPi Shield.sch at 6/23/2019 4:01 PM

Part           Value                  Device                 Package            Description                                            MF MPN        OC_FARNELL OC_NEWARK PACKAGE SPICEMODEL SPICEPREFIXL SUPPLIER         
ALARM          2 pin                  HEADER02-1             HEADER02-1         PIN HEADER                                                                                                                                 
BACKLIGHT      3 pin                  HEADER03-1             HEADER03-1         PIN HEADER                                                           unknown    unknown                                                    
C1             0.1μF                  CAPKIT                 CAP-PTH-SMALL-KIT  Capacitor                                                                                                                                  
C2             0.1μF                  CAPKIT                 CAP-PTH-SMALL-KIT  Capacitor                                                                                                                                  
C3             0.1μF                  CAPKIT                 CAP-PTH-SMALL-KIT  Capacitor                                                                                                                                  
C4             0.1μF                  CAPKIT                 CAP-PTH-SMALL-KIT  Capacitor                                                                                                                                  
C5             0.1μF                  CAPKIT                 CAP-PTH-SMALL-KIT  Capacitor                                                                                                                                  
C6             0.1μF                  CAPKIT                 CAP-PTH-SMALL-KIT  Capacitor                                                                                                                                  
C7             0.1μF                  CAPKIT                 CAP-PTH-SMALL-KIT  Capacitor                                                                                                                                  
C8             1.0μF                  CAPKIT                 CAP-PTH-SMALL-KIT  Capacitor                                                                                                                                  
COOL_LED       3 pin                  HEADER03-1             HEADER03-1         PIN HEADER                                                           unknown    unknown                                                    
DOOR           2 pin                  HEADER02-1             HEADER02-1         PIN HEADER                                                                                                                                 
HEAT_LED       3 pin                  HEADER03-1             HEADER03-1         PIN HEADER                                                           unknown    unknown                                                    
I2C_LED        4 pin                  HEADER04-1             HEADER04-1         PIN HEADER                                                           unknown    unknown                                                    
J1             ARDUINO_R3_SHIELD_ICSP ARDUINO_R3_SHIELD_ICSP UNO_R3_SHIELD_ICSP Arduino R3 Shield Footprint w/ 6-pin (2x3) ICSP Header                                                                                     
ONE_WIRE_SEL   3 pin                  HEADER03-1             HEADER03-1         PIN HEADER                                                           unknown    unknown                                                    
PARALLEL_LCD_1 6 pin                  HEADER06-1             HEADER06-1         PIN HEADER                                                           unknown    unknown                                                    
PARALLEL_LCD_2 6 pin                  HEADER06-1             HEADER06-1         PIN HEADER                                                           unknown    unknown                                                    
PROBE1         3 pin                  HEADER03-1             HEADER03-1         PIN HEADER                                                           unknown    unknown                                                    
PROBE2         3 pin                  HEADER03-1             HEADER03-1         PIN HEADER                                                           unknown    unknown                                                    
PROBE3         3 pin                  HEADER03-1             HEADER03-1         PIN HEADER                                                           unknown    unknown                                                    
Q1             2N3906                 2N3906                 TO92               PNP Transistor                                                                                                                             
R1             10kΩ                   R-TRIMM3296Y           RTRIM3296Y         Trimm resistor                                                                                    X          POT                           
R2             20kΩ                   RESISTORAXIAL-0.3      AXIAL-0.3          Resistor                                                                                                                                   
R3             10kΩ                   RESISTORAXIAL-0.3      AXIAL-0.3          Resistor                                                                                                                                   
R4             10kΩ                   RESISTORAXIAL-0.3      AXIAL-0.3          Resistor                                                                                                                                   
R5             10kΩ                   RESISTORAXIAL-0.3      AXIAL-0.3          Resistor                                                                                                                                   
R6             4.7kΩ                  RESISTORAXIAL-0.3      AXIAL-0.3          Resistor                                                                                                                                   
R7             2kΩ                    RESISTORAXIAL-0.3      AXIAL-0.3          Resistor                                                                                                                                   
R8             1kΩ                    RESISTORAXIAL-0.3      AXIAL-0.3          Resistor                                                                                                                                   
R9             220Ω                   RESISTORAXIAL-0.3      AXIAL-0.3          Resistor                                                                                                                                   
R10            220Ω                   RESISTORAXIAL-0.3      AXIAL-0.3          Resistor                                                                                                                                   
R11            150Ω                   RESISTORAXIAL-0.3      AXIAL-0.3          Resistor                                                                                                                                   
R12            10kΩ                   RESISTORAXIAL-0.3      AXIAL-0.3          Resistor                                                                                                                                   
RELAY          4 pin                  HEADER04-1             HEADER04-1         PIN HEADER                                                           unknown    unknown                                                    
RJ45           RJ45-8X                RJ45-8X                RJ45-NO-SHIELD     CORCOM Modular RJ Jacks No Shield                         RJ45-8X    unknown    16R6101                                                    
ROT_ENC        4 pin                  HEADER04-1             HEADER04-1         PIN HEADER                                                           unknown    unknown                                                    
SERIAL         4 pin                  HEADER04-1             HEADER04-1         PIN HEADER                                                           unknown    unknown                                                    
U1             SN74HC595N             SN74HC595N             DIP254P762X508-16  8-BIT SHIFT REGISTERS WITH 3-STATE OUTPUT REGISTERS       SN74HC595N 9591664    60K6845   PDIP-16                         Texas Instruments

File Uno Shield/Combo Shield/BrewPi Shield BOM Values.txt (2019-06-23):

Partlist exported from C:/Users/lee/OneDrive/Desktop/BrewPi/Git/brewpi-pcb-rmx/shield/BrewPi Shield.sch at 6/23/2019 4:02 PM

Qty Value                  Device                 Package            Parts                                                               Description                                            MF MPN        OC_FARNELL OC_NEWARK PACKAGE SPICEMODEL SPICEPREFIXL SUPPLIER         
7   0.1μF                  CAPKIT                 CAP-PTH-SMALL-KIT  C1, C2, C3, C4, C5, C6, C7                                          Capacitor                                                                                                                                  
1   1.0μF                  CAPKIT                 CAP-PTH-SMALL-KIT  C8                                                                  Capacitor                                                                                                                                  
1   10kΩ                   R-TRIMM3296Y           RTRIM3296Y         R1                                                                  Trimm resistor                                                                                    X          POT                           
4   10kΩ                   RESISTORAXIAL-0.3      AXIAL-0.3          R3, R4, R5, R12                                                     Resistor                                                                                                                                   
1   150Ω                   RESISTORAXIAL-0.3      AXIAL-0.3          R11                                                                 Resistor                                                                                                                                   
1   1kΩ                    RESISTORAXIAL-0.3      AXIAL-0.3          R8                                                                  Resistor                                                                                                                                   
2   2 pin                  HEADER02-1             HEADER02-1         ALARM, DOOR                                                         PIN HEADER                                                                                                                                 
1   20kΩ                   RESISTORAXIAL-0.3      AXIAL-0.3          R2                                                                  Resistor                                                                                                                                   
2   220Ω                   RESISTORAXIAL-0.3      AXIAL-0.3          R9, R10                                                             Resistor                                                                                                                                   
1   2N3906                 2N3906                 TO92               Q1                                                                  PNP Transistor                                                                                                                             
1   2kΩ                    RESISTORAXIAL-0.3      AXIAL-0.3          R7                                                                  Resistor                                                                                                                                   
7   3 pin                  HEADER03-1             HEADER03-1         BACKLIGHT, COOL_LED, HEAT_LED, ONE_WIRE_SEL, PROBE1, PROBE2, PROBE3 PIN HEADER                                                           unknown    unknown                                                    
4   4 pin                  HEADER04-1             HEADER04-1         I2C_LED, RELAY, ROT_ENC, SERIAL                                     PIN HEADER                                                           unknown    unknown                                                    
1   4.7kΩ                  RESISTORAXIAL-0.3      AXIAL-0.3          R6                                                                  Resistor                                                                                                                                   
2   6 pin                  HEADER06-1             HEADER06-1         PARALLEL_LCD_1, PARALLEL_LCD_2                                      PIN HEADER                                                           unknown    unknown                                                    
1   ARDUINO_R3_SHIELD_ICSP ARDUINO_R3_SHIELD_ICSP UNO_R3_SHIELD_ICSP J1                                                                  Arduino R3 Shield Footprint w/ 6-pin (2x3) ICSP Header                                                                                     
1   RJ45-8X                RJ45-8X                RJ45-NO-SHIELD     RJ45                                                                CORCOM Modular RJ Jacks No Shield                         RJ45-8X    unknown    16R6101                                                    
1   SN74HC595N             SN74HC595N             DIP254P762X508-16  U1                                                                  8-BIT SHIFT REGISTERS WITH 3-STATE OUTPUT REGISTERS       SN74HC595N 9591664    60K6845   PDIP-16                         Texas Instruments

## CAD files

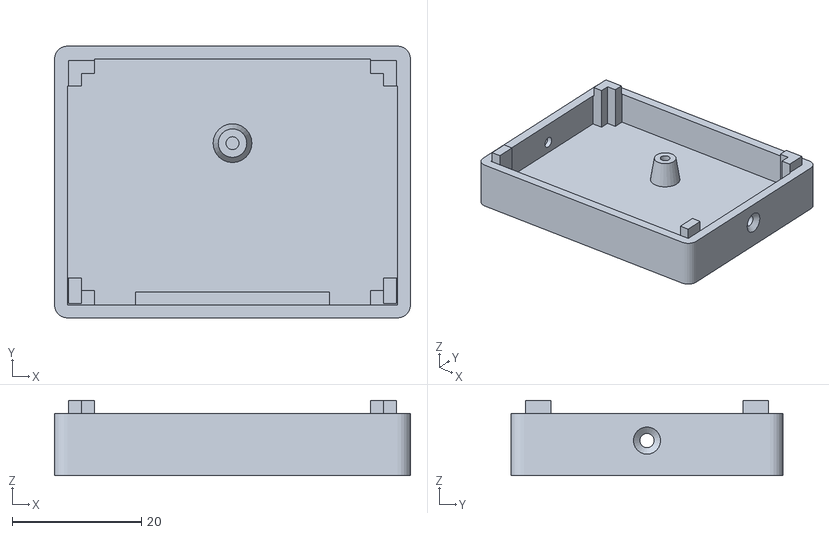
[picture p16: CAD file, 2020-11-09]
RJ45 Breakout/RJ45 Breakout Enclosure - Bottom.stl
55.0 x 42.0 x 11.6

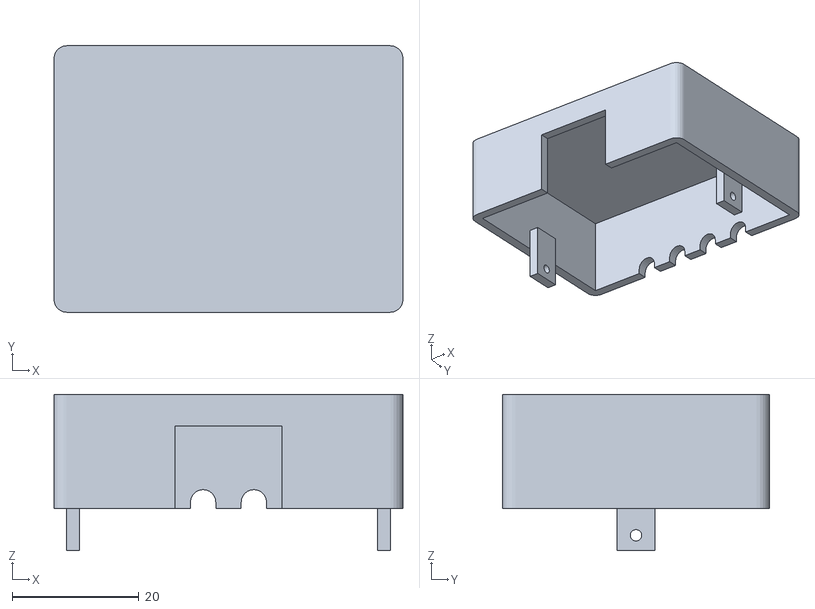
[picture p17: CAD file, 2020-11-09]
RJ45 Breakout/RJ45 Breakout Enclosure - Top.stl
55.0 x 42.0 x 24.6

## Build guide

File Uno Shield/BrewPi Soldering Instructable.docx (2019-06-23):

LCB Note: This Instructable was written for v1.1. It is not exactly correct for this version, however still contains good information.

BrewPi LCD Shield Instructable

If you’re interested in adding an LCD screen, Bluetooth connectivity, a rotary encoder to control your BrewPi without having to open up your Raspberry Pi, or all of the above, the BrewPi shield is an easy way to add the functionality without having to know or understand electronics. The shield was based on the work of day_trippr on Homebrewtalk.com and his LCD and Bluetooth “how-to’s”. The shield simply takes his protoshield design and incorporates it into a printed circuit board that you can more easily solder up.

Ordering a PCB Board

The first thing you’ll need is a PCB board. You can download the files here (https://drive.google.com/folderview?id=0BwakCoACNDsmSWNQeS0xNVBBRFk&usp=sharing), or you can go straight to OshPark and access the project here (https://oshpark.com/shared_projects/rcOadziH). The files are in Eaglesoft and are the board and schematic files. You can use these files to order boards directly from OshPark or Dirt Cheap Boards. If you go to other board houses, you’ll likely need to create a Gerber file to order boards. There are numerous resources on the web for how to create Gerber files.

OshPark and Dirt Cheap Boards both charge approximately $25 for a run of boards. At OshPark, you’ll get 3 for that price. At Dirt Cheap Boards, you’ll get anywhere from 9 to 11, depending upon their manufacturing run that day. You’ll need one board for every instance of BrewPi you would like to build.

Components

Once you have the board, you’ll need to populate it with the following components. You’ll also need male pin “breakaway” headers and stackable headers. You can find Arduino Stackable Headers at Adafruit.com, but any long male pin headers will work. The list below is just the shield components. You’ll need an LCD screen, Bluetooth module, rotary encoder, and whatever other components you need to build your custom BrewPi box.

Part number | Part type | Value
C1 – C7 | Capacitor | .1uF
C8 | Capacitor | 1.0uF
R1 | Trimmer Resistor | 10k, three lead trim pot – offset leads
R2 – R5 | Resistor | 10k ¼ W
R6 | Resistor | 4.7k ¼ W
R7 | Resistor | 1K ¼ W
R8 | Resistor | 2K ¼ W
R9, R11 | Resistor | 220 ¼ W
R10 | Resistor | 20 ½ W
D1 – D2 | Diode | 1N4007
U1 | IC | 74HC595N – optional but recommended, an IC socket for mounting on the board
U2 | P-FET | BSS84

Assembly

When you have your board and components, let the assembly begin! Here’s your empty board. Clean up any rough edges of the board with side clipping pliers and sandpaper.

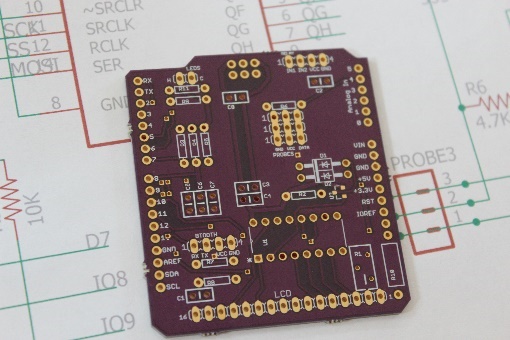
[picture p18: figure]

There are many references for soldering up electronics on the web. You can find inexpensive soldering irons on Ebay or Amazon. I have found that a good soldering station with a holder for the iron, a small tip for the iron, a place for a wet sponge and a variable adjustment on the heat are all you need. Add to that some flux, a pair of needle nosed pliers, some side cutting pliers, and a “third hand” with clamps and a magnifying glass all come in handy and are useful on this project and others you will undoubtedly tackle in the future.

P-Fet

The first component I start with when soldering the board is the P-Fet. It is indescribably small. Sure, you could measure it and then describe how small it is in millimeters, but that does not do it justice. They arrive in a small protective pack. Even the pack is small, and getting it open without damaging the tiny guy inside is a challenge. If you get it open and haven’t dropped it into your 1970’s shag carpet, you’re well on your way to success.

Here it is in relation to the board.

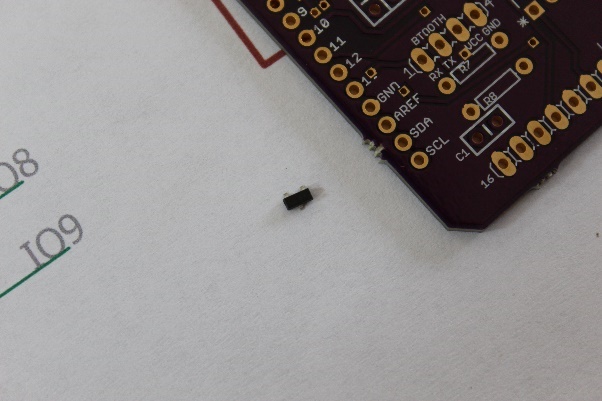
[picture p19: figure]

I start with the P-Fet because it is easier to solder it up without having to work around the headers and other components on the board. Check out a few tutorials on the web on soldering “surface mount” components. It isn’t too difficult if you’re patient. When you get through it, bask in the joy of knowing that you’ve tackled the hardest part of the entire build. FWIW, I solder it up by flowing a small amount of flux onto each of the three pads, then carefully placing the P-Fet onto the pad with some tweezers or pliers, then heating one leg to flow the solder onto the leg. Once the first leg is soldered, you can flow solder onto the other two. Hopefully yours will look cleaner than mine when you’re done, but know that even as ugly as this, it works.

It should be fairly obvious where it lives on the board and the orientation. The label might be slightly obscured, but it is labeled U2 and has 3 pads.

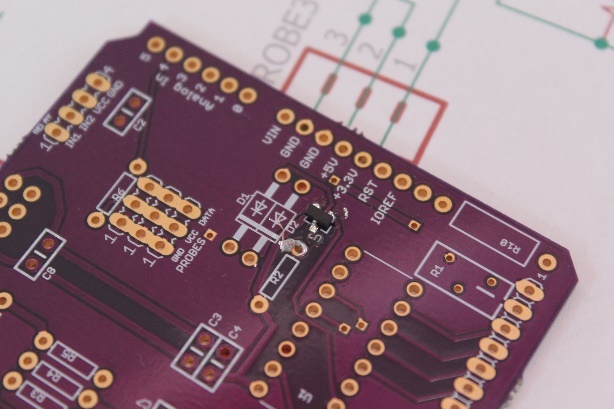
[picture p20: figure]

Resistors

With the P-F’er (as we lovingly call it in my house) behind you, let’s move on to the resistors. There is no orientation to the resistors, so put them in any fashion you desire. I solder them all up at the same time. Just put the leads into the holes and then bend the leads on the back in order to keep the resistor in place while you solder them up.

R2 – R5 | Resistor | 10k ¼ W
R6 | Resistor | 4.7k ¼ W
R7 | Resistor | 1K ¼ W
R8 | Resistor | 2K ¼ W
R9, R11 | Resistor | 220 ¼ W
R10 | Resistor | 20 ½ W

Here’s what they look like before and after soldering. Trim the leads after you’ve soldered them all up.

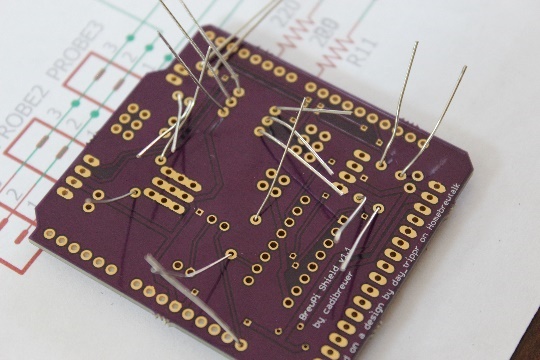
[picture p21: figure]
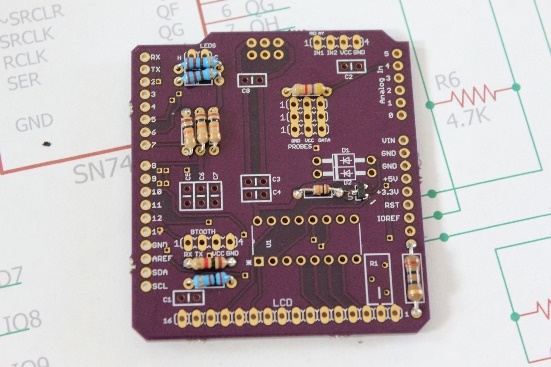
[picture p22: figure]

Capacitors

Soldering the capacitors is just like the resistors. No orientation, no problem. Put them in, bend the leads, solder them up. Make sure you get the largest capacitor in C8.

C1 – C7 | Capacitor | .1uF
C8 | Capacitor | 1.0uF

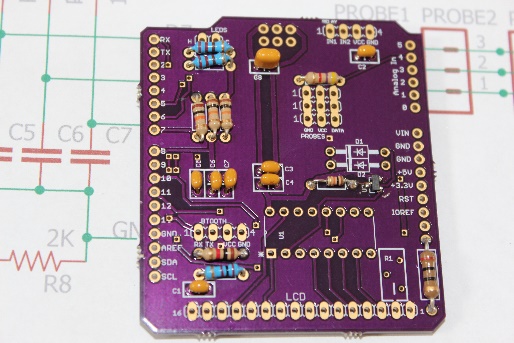
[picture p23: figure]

Diodes

The diodes have a polarized orientation. The silkscreen on the board has a heavy line and picture to help you orient them in the right direction. Solder them up like the resistors and capacitors.

D1 – D2 | Diode | 1N4007

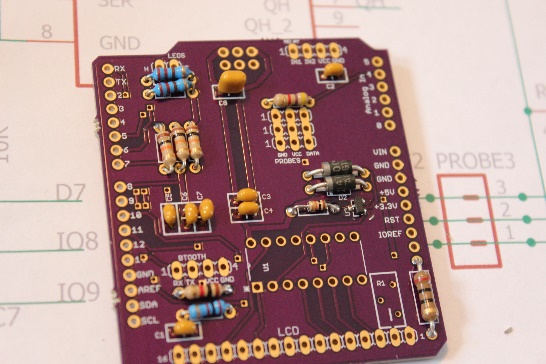
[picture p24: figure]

Trimmer

The trim pot goes in R1. If you ordered the right one, the legs will be offset and it will be apparent how to orient it in the slot. Solder it up.

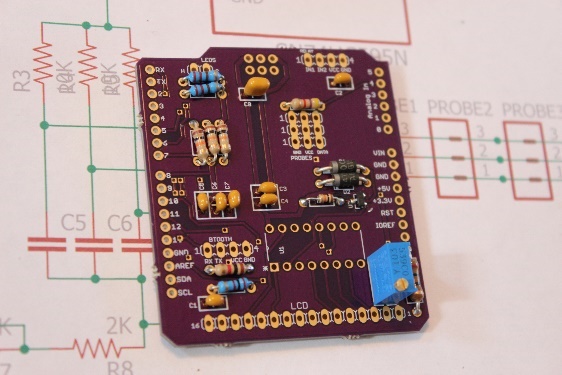
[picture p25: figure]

IC Socket

You can solder the IC right to the board, but I would suggest using a socket. Any 16 pin IC socket will work. There is a notch on the socket and a corresponding notch on the board silkscreen to help with orientation. Put the socket on the board and solder it up from the back.

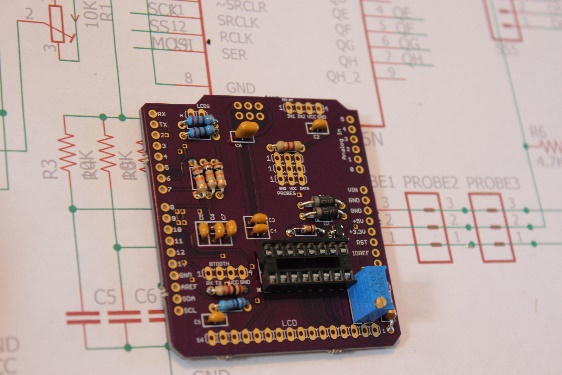
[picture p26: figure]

Stackable Headers

I used Arduino Stackable Headers, ordered from Adafruit.com. It would be better if you can find extra-long male pins so that you can use female socket jumper wires when you hook up the rotary encoder later on. If you use the stackable headers I used, you’ll have to use male jumper wires, which are taller and not as secure in their connection. Be smarter than I am.

Put the headers on the board and solder them up from the back. A trick I have found for getting them straight and aligned is to solder only one of the pins and then check the alignment. If it needs adjusting, simply heat the solder with your iron while moving the header with your other hand. You can reposition the header as you like and then let the solder cool. Then solder up the rest of the pins and you’ll have a straight installation.

Note- The 6 pins in the 2x3 configuration need to be soldered from the top of the board so that your sockets are under on the back side. This is important because your board will not mate up with the Arduino Uno if you solder on the wrong side.

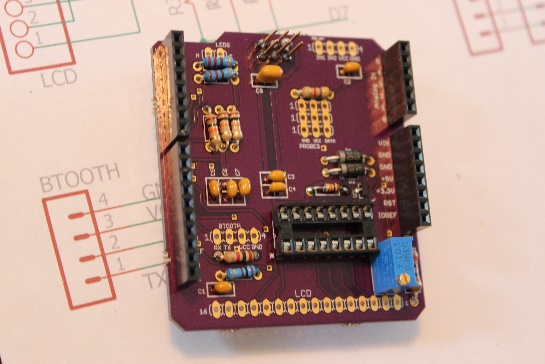
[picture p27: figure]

Component Headers

The headers for the LCD screen, Bluetooth, relay, probes, and LEDs are soldered in the same way. Cut the breakaway headers to the correct length using your diagonal cutting pliers. Solder them from the back with the long pins on the top of the board.

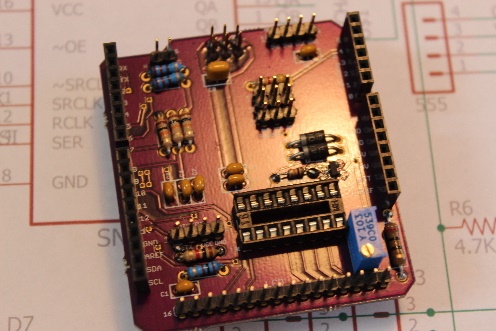
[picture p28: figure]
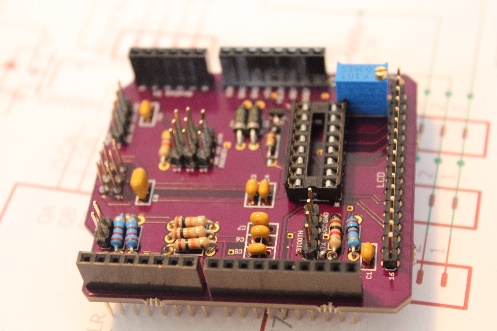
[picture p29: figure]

Use

That’s it, your board is done! You can insert the IC into the socket and then mate your new shield to your UNO. Hook up your LCD screen to the header and then adjust the brightness of the screen with the small screw on the trim pot.

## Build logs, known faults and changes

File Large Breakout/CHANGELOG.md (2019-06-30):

# Rotary Encoder Breakout Changelog
All notable changes to this project will be documented in this file.

The format is based on [Keep a Changelog](https://keepachangelog.com/en/1.0.0/),
and this project adheres to [Semantic Versioning](https://semver.org/spec/v2.0.0.html).

## [v1.3.1a] - 2019-06-30
Cosmetic change, minor re-write

### Added
 - N/A

### Changed
- Update logo

## [v1.3] - 2019-05-31
This breakout is mainly intended to display all of the potential functionality which can be incorporated in such a board.  Smaller, more specific versions can be created from this example.
### Added
- Initial release

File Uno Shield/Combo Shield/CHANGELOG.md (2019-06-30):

# Arduino Shield Changelog
All notable changes to this project will be documented in this file.

The format is based on [Keep a Changelog](https://keepachangelog.com/en/1.0.0/),
and this project adheres to [Semantic Versioning](https://semver.org/spec/v2.0.0.html).

## [v1.3.1a] - 2019-06-30
Mostly adjustments after having the first fab run done

### Added
  - N/A

### Changed
  - Silk screens for backlight and OneWire selector moved for visibility
  - Removed some vias and re-routed some traces

### Removed
  - N/A

## [v1.3.1] - 2019-06-02
Update to allow flexible configuration of the backlight.

### Added
  - Jumper cap header to select between backlight on a timer (requires rotary encoder or a button to wake it up) vs having the backlight always on.

### Changed
  - R12 now provides sink for transistor in either backlight configuration.

### Removed
  - Removed R13

## [v1.3] - 2019-06-01
This is v1.3, code named: "The One Shield."  I can't see where we can do anything different with the Arduino Uno.  Perhaps most significantly, this shield provides hardware support for an I2C display (there's important information about this below).  There are other improvements which I think you guys are gonna dig.

If you want to use the I2C there are two important things you need to keep in mind!
1.	I2C support is a separate firmware image and only available in version 0.2.12.  As of right now (6/1/19) this is a beta image, but I should be ready to release it soon.  Firmware 0.2.12 requires BrewPi Scripts/WWW v0.5.2.1 which is currently in the Devel branch.
2.	You MUST select "A0" on the One-Wire selector.

### Added
 - Four-pin I2C header.  No more having to use that 16-pin ribbon!  A mere 4 wires to connect your display. (Yes, the previous parallel LCD is supported as well.)
 - Rotary encoder header - No more having to figure out which Arduino header pins to use!
 - OneWire Selection: One each three-pin header to switch between A0 or A4 for the One-Wire bus.  You must use A0 if you are using I2C.  Not sure why Elco ever used A4 but that's one of the hard-wired I2C pins for the Arduino so a chance was necessary.
 - Break-Out Board support:  An RJ45 to allow for a remote break-out board.  This uses an Ethernet cable (which is straight-through) as opposed to the smaller RJ11 (telephone cord) because phone cords are cross-over by default.  The pin-out supports [USER=221138]@Thorrak[/USER]'s original breakout boards, however support for remotely placing the heat/cool relays is also included.  A breakout board supporting all of this is in development:
   - Pin 1 - Unused
   - Pin 2 - Unused
   - Pin 3 - VCC
   - Pin 4 - OneWire Data (A4 or A0)
   - Pin 5 - GND
   - Pin 6 - Door (D4)
   - Pin 7 - Cool (D5)
   - Pin 8 - Heat (D6)
  - Door pins:  The original Arduino firmware has support for a contact switch which detects when the door is open.  I don't know of many folks using this but adding two pins for that was easy enough since we already put it on the RJ45.
  - Alarm:  The original firmware has VERY basic support for an alarm (piezo speaker).  Right now, it only beeps when the Arduino resets but maybe we can do something more with it later.
  - LCD Backlight always-on:  If one used the v1.2 board with no rotary encoder or at least a switch, the LCD would time-out and not be able to be turned back on.  Added R13 to keep the backlight always-on in those cases.  To make use of this functionality, REMOVE R12 and ADD R13.

### Changed
  - LED headers - The old headers were one pin each for heat and cool, connected to a pull-up resistor.  That worked fine with "normal" setups, but the wiring was not straightforward for what I call "mere mortals." And, if you used non-inverted outputs for heat and cool (such as with SRs) you found yourself in a strange position.  These headers are three-pin: VCC <-> D5/6 <-> GND.  This means if you are using "normal" inverted outputs, you connect your LEDs to VCC and the center pin for either LED.  If you are using non-inverted outputs, you connect the LEDs to GND and the center pin for either LED.
  - Relays: This change re-orders the pins to match the typical relay headers.
  - Power:  Version 1.2 split the power for the LCD and used the ICSP header to power the LCD backlight to reduce LCD scrambling.  By all accounts that had no impact.  On some Arduino clones (as well as the combo ESP8266/ATmega328P boards) have the ICSP header in a different place, which ended up requiring jumpers to apply power to the LCD, and/or creating a shorting point with the pins hitting an unexpected place on the controller board.  This has been re-combined with the power and ground points looped together to form a single larger bus.  In addition, from v0.2.11 of the Arduino firmware, there is a timer which resets the LCD display every 180 seconds to get rid of any scrambling.
  - Parallel LCD header:  Even though the old header was 16-pins, we only used 12 of them.  Using a straight 16 was simpler and kept people form screwing things up too bad but we needed the room.  So, the parallel LCD header is now split into two 6-pin headers.  This does give the benefit of making this connection much easier to route as bending two 6-wire ribbons is a lot easier than a 16-wire one.

### Removed
- N/A

## [v1.2] - 2014-07-10
### Changed
- Replaced mosfet with transistor for easier assembly.

## [v1.1] - 2017-01-27
### Added
- Original version, unknown release date

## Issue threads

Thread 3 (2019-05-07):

Need I2C Shield

lbussy, 2019-05-07:
Need a new shield design for I2C support, since the pinouts have changes.

lbussy, 2019-07-01:
Closed with [this pull](https://github.com/brewpi-remix/brewpi-pcb-rmx/pull/2).

Closed 2019-07-01.

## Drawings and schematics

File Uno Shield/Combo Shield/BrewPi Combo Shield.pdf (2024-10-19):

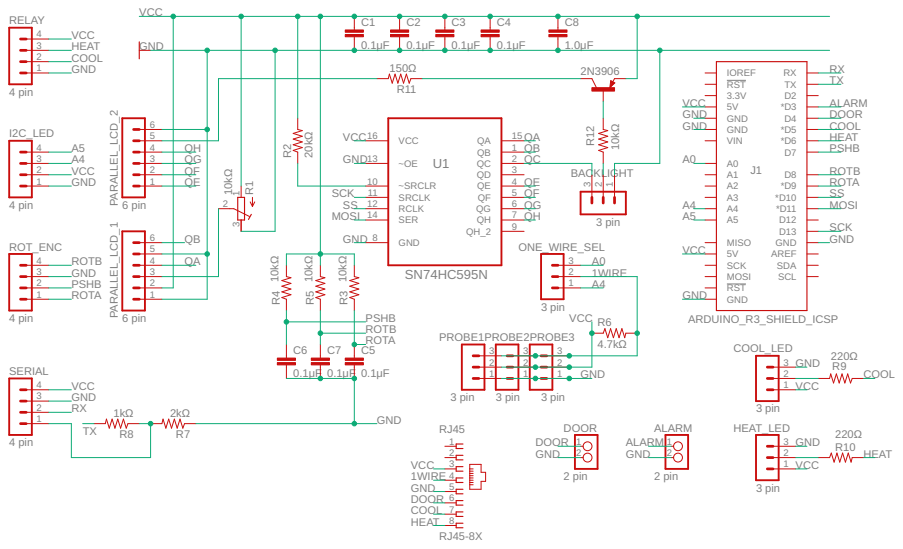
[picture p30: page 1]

SCL MISO
SCK MOSI RST GND

1 | 1 | 1 GND

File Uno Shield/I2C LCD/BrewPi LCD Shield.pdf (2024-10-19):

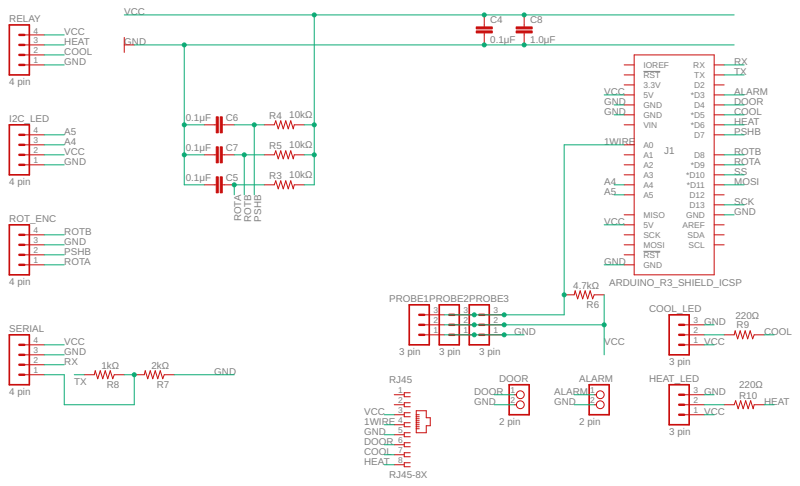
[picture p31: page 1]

SCL MISO
SCK MOSI RST GND

1 | 1 | 1 GND

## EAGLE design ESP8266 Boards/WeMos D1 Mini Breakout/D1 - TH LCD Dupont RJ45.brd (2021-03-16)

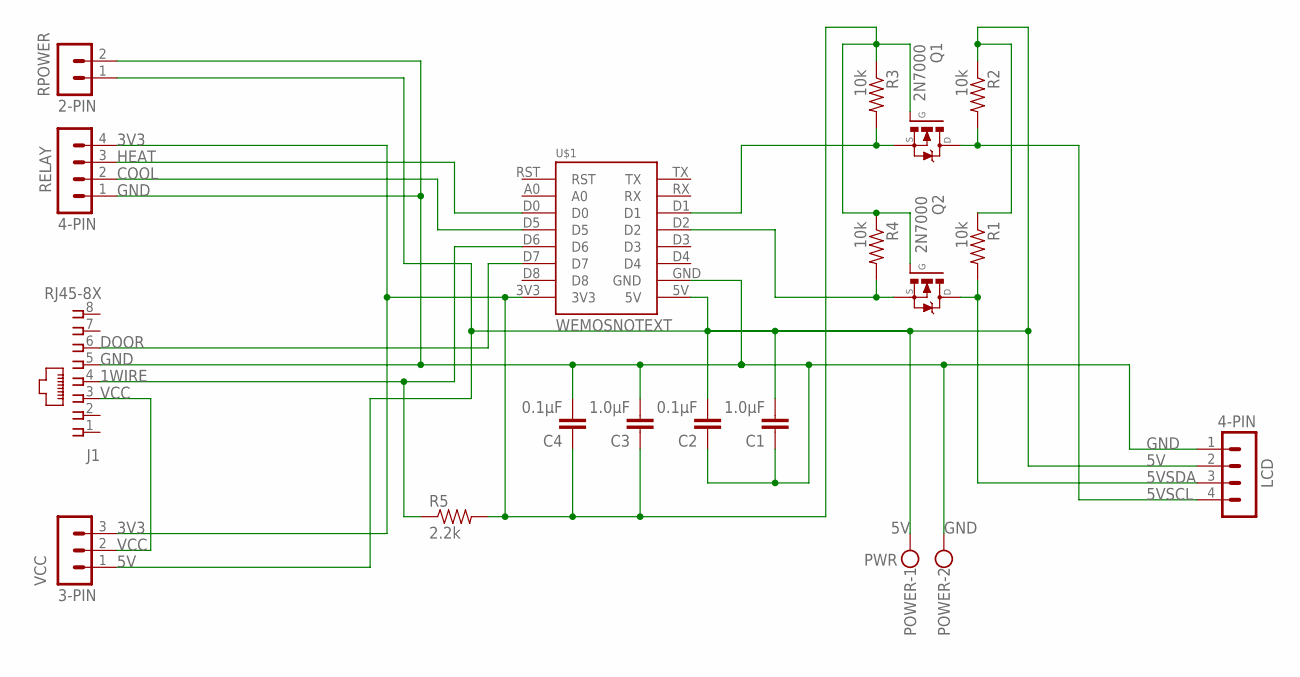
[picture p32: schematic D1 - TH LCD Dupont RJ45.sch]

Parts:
C1, C3: 1.0μF; CAP_PTH-2.54
C2, C4: 0.1μF; CAP_PTH-2.54
J1: RJ45-8X; RJ45-NO-SHIELD-NOLINE
LCD: 4-PIN; HDR-4_VERT
POWER: PWR; W237-102
Q1, Q2: 2N7000; TO-92
R1, R2, R3, R4: 10k; AXIAL-0.3
R5: 2.2k; AXIAL-0.3
RELAY: 4-PIN; HDR-4_VERT
RPOWER: 2-PIN; HDR-2_VERT
U$1: WEMOSNOTEXT; WEMOS_D1-NOTEXT
VCC: 3-PIN; MA03-1

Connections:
1WIRE: J1.4, R5.P$1 (1), U$1.D6
3V3: C3.1, C4.1, Q1.2 (G), Q2.2 (G), R3.P$1 (1), R4.P$1 (1), R5.P$2 (2), RELAY.4, U$1.3V3, VCC.3
3VSCL: Q1.1 (S), R3.P$2 (2), U$1.D1
3VSDA: Q2.1 (S), R4.P$2 (2), U$1.D2
5V: C1.2, C2.2, LCD.2, POWER.1, R1.P$1 (1), R2.P$1 (1), RPOWER.1, U$1.5V, VCC.1
5VSCL: LCD.4, Q1.3 (D), R2.P$2 (2)
5VSDA: LCD.3, Q2.3 (D), R1.P$2 (2)
COOL: RELAY.2, U$1.D5
DOOR: J1.6, U$1.D7
GND: C1.1, C2.1, C3.2, C4.2, J1.5, LCD.1, POWER.2, RELAY.1, RPOWER.2, U$1.GND
HEAT: RELAY.3, U$1.D0
VCC: J1.3, VCC.2

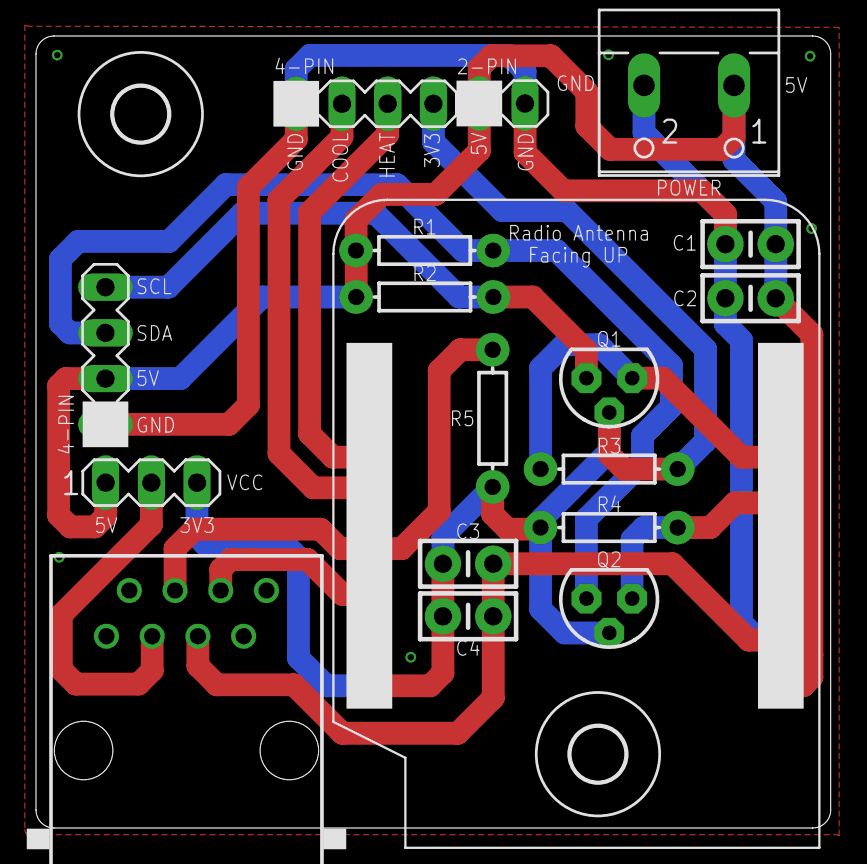
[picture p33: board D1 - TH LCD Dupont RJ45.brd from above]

Board: 2 copper layers, 44.1 x 44.0 mm, 20 parts (0 on the bottom side), 12 nets.

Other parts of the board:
U$2, U$4: 3,0

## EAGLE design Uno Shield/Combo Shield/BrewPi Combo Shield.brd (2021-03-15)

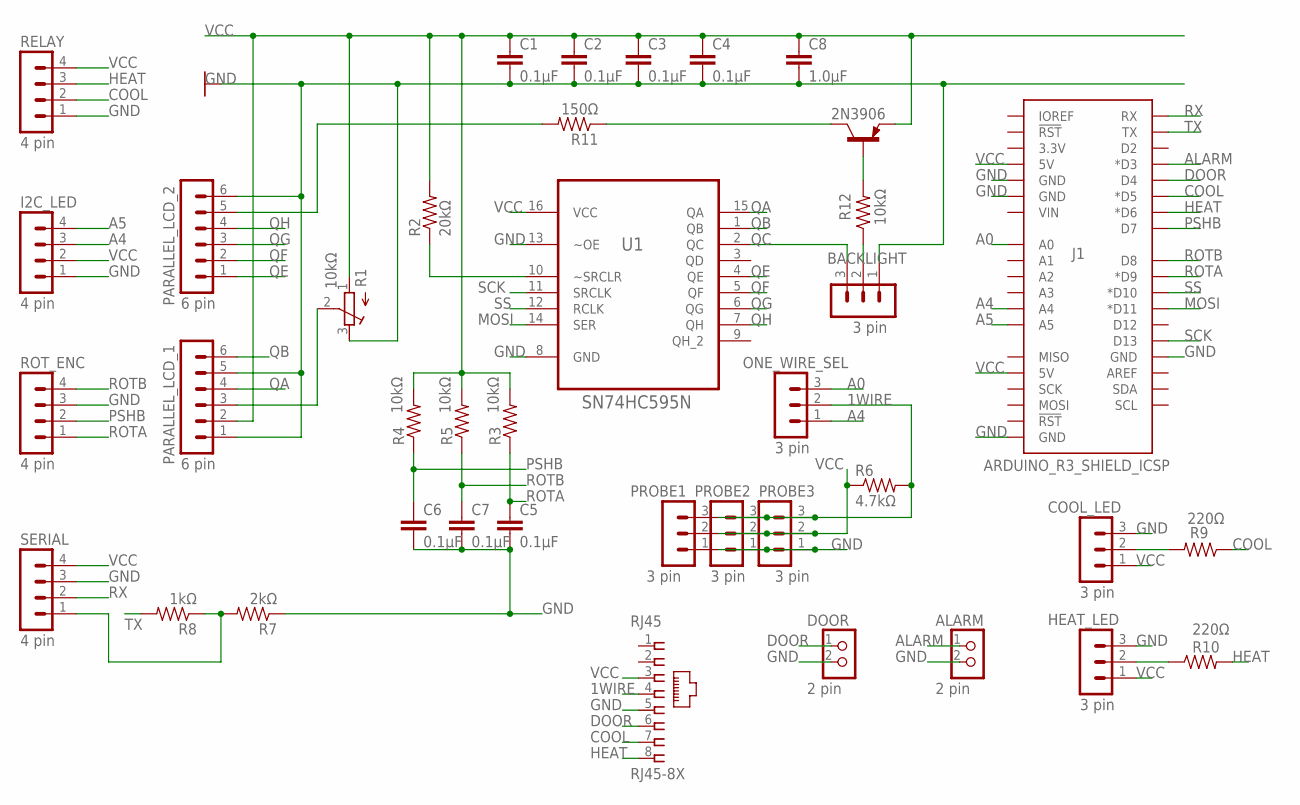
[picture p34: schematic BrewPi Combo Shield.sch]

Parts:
ALARM: 2 pin; HEADER02-1
BACKLIGHT: 3 pin; HEADER03-1
C1, C2, C3, C4, C5, C6, C7: 0.1μF; CAP-PTH-SMALL-KIT
C8: 1.0μF; CAP-PTH-SMALL-KIT
COOL_LED: 3 pin; HEADER03-1
DOOR: 2 pin; HEADER02-1
HEAT_LED: 3 pin; HEADER03-1
I2C_LED: 4 pin; HEADER04-1
J1: ARDUINO_R3_SHIELD_ICSP; UNO_R3_SHIELD_ICSP
ONE_WIRE_SEL: 3 pin; HEADER03-1
PARALLEL_LCD_1, PARALLEL_LCD_2: 6 pin; HEADER06-1
PROBE1, PROBE2, PROBE3: 3 pin; HEADER03-1
Q1: 2N3906; TO92
R1: 10kΩ; RTRIM3296Y
R2: 20kΩ; AXIAL-0.3
R3, R4, R5, R12: 10kΩ; AXIAL-0.3
R6: 4.7kΩ; AXIAL-0.3
R7: 2kΩ; AXIAL-0.3
R8: 1kΩ; AXIAL-0.3
R9, R10: 220Ω; AXIAL-0.3
R11: 150Ω; AXIAL-0.3
RELAY: 4 pin; HEADER04-1
RJ45: RJ45-8X; RJ45-NO-SHIELD
ROT_ENC: 4 pin; HEADER04-1
SERIAL: 4 pin; HEADER04-1
U1: SN74HC595N; DIP254P762X508-16

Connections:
1WIRE: ONE_WIRE_SEL.2, PROBE1.3, PROBE2.3, PROBE3.3, R6.P$2 (2), RJ45.4
A0: J1.A0, ONE_WIRE_SEL.3
A4: I2C_LED.3, J1.A4, ONE_WIRE_SEL.1
A5: I2C_LED.4, J1.A5
ALARM: ALARM.1, J1.D3 (*D3)
COOL: J1.D5 (*D5), R9.P$1 (1), RELAY.2, RJ45.7
DOOR: DOOR.1, J1.D4, RJ45.6
GND: ALARM.2, BACKLIGHT.1, C1.2, C2.2, C3.2, C4.2, C5.2, C6.2, C7.2, C8.2, COOL_LED.3, DOOR.2, HEAT_LED.3, I2C_LED.1, J1.GND@0 (GND), J1.GND@1 (GND), J1.GND@2 (GND), J1.GND_ICSP (GND), PARALLEL_LCD_1.1, PARALLEL_LCD_1.5, PARALLEL_LCD_2.6, PROBE1.1, PROBE2.1, PROBE3.1, R1.3 (E), R7.P$1 (1), RELAY.1, RJ45.5, ROT_ENC.3, SERIAL.3, U1.8 (GND), U1.13 (~OE)
HEAT: J1.D6 (*D6), R10.P$2 (2), RELAY.3, RJ45.8
MOSI: J1.D11 (*D11), U1.14 (SER)
unnamed: R2.P$1 (1), U1.10 (~SRCLR)
unnamed: BACKLIGHT.2, R12.P$1 (1)
unnamed: R7.P$2 (2), R8.P$1 (1), SERIAL.1
unnamed: COOL_LED.2, R9.P$2 (2)
unnamed: PARALLEL_LCD_2.5, R11.P$2 (2)
unnamed: PARALLEL_LCD_1.3, R1.2 (S)
unnamed: Q1.1 (C), R11.P$1 (1)
unnamed: HEAT_LED.2, R10.P$1 (1)
unnamed: Q1.2 (B), R12.P$2 (2)
PSHB: C6.1, J1.D7, R4.P$1 (1), ROT_ENC.2
QA: PARALLEL_LCD_1.4, U1.15 (QA)
QB: PARALLEL_LCD_1.6, U1.1 (QB)
QC: BACKLIGHT.3, U1.2 (QC)
QE: PARALLEL_LCD_2.1, U1.4 (QE)
QF: PARALLEL_LCD_2.2, U1.5 (QF)
QG: PARALLEL_LCD_2.3, U1.6 (QG)
QH: PARALLEL_LCD_2.4, U1.7 (QH)
ROTA: C5.1, J1.D9 (*D9), R3.P$1 (1), ROT_ENC.1
ROTB: C7.1, J1.D8, R5.P$1 (1), ROT_ENC.4
RX: J1.RX, SERIAL.2
SCK: J1.D13, U1.11 (SRCLK)
SS: J1.D10 (*D10), U1.12 (RCLK)
TX: J1.TX, R8.P$2 (2)
VCC: C1.1, C2.1, C3.1, C4.1, C8.1, COOL_LED.1, HEAT_LED.1, I2C_LED.2, J1.5V, J1.5V_ICSP (5V), PARALLEL_LCD_1.2, PROBE1.2, PROBE2.2, PROBE3.2, Q1.3 (E), R1.1 (A), R2.P$2 (2), R3.P$2 (2), R4.P$2 (2), R5.P$2 (2), R6.P$1 (1), RELAY.4, RJ45.3, SERIAL.4, U1.16 (VCC)

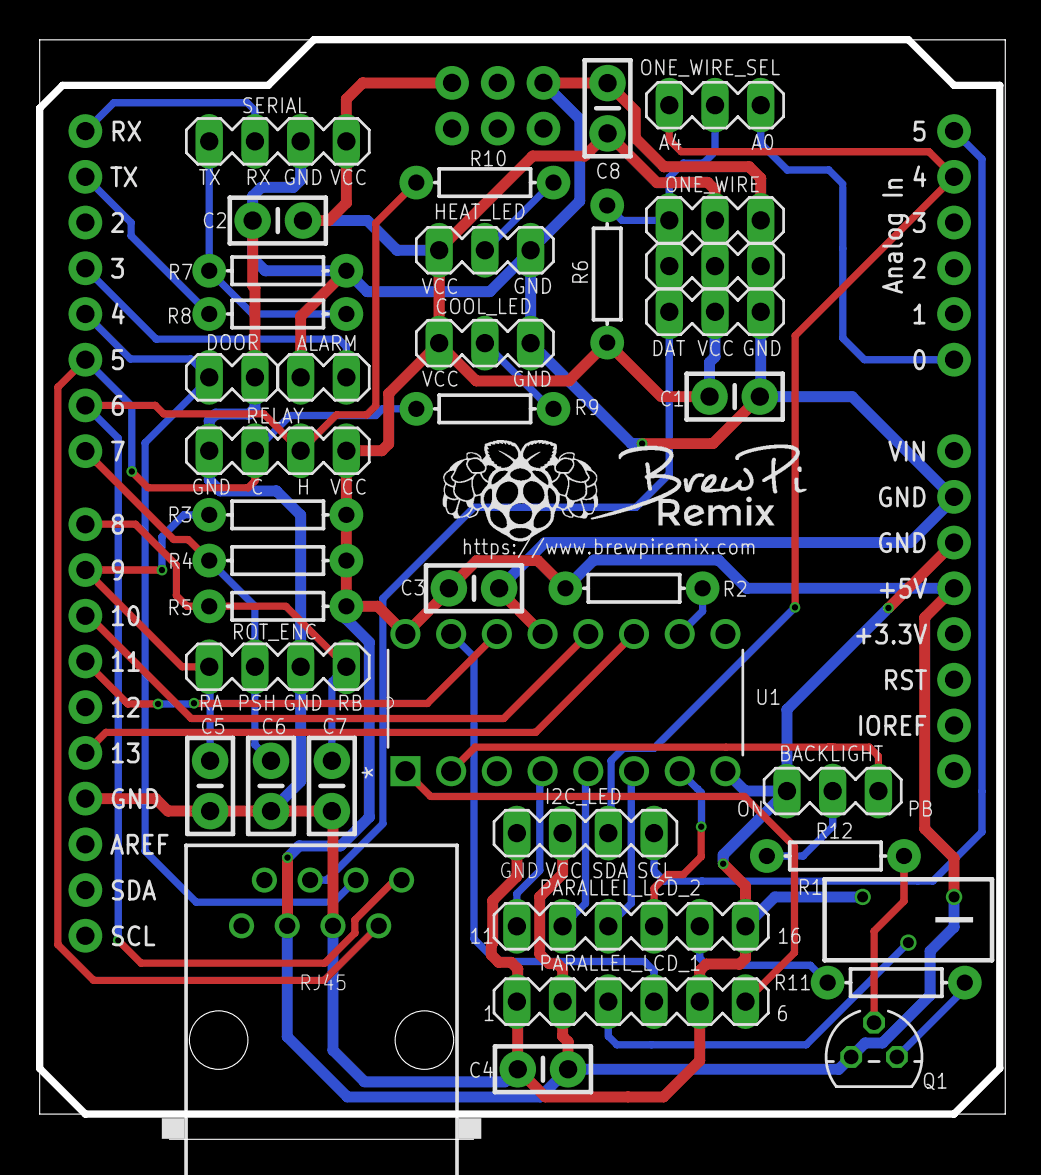
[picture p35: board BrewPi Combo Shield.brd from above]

Board: 2 copper layers, 53.6 x 61.1 mm, 39 parts (0 on the bottom side), 34 nets.

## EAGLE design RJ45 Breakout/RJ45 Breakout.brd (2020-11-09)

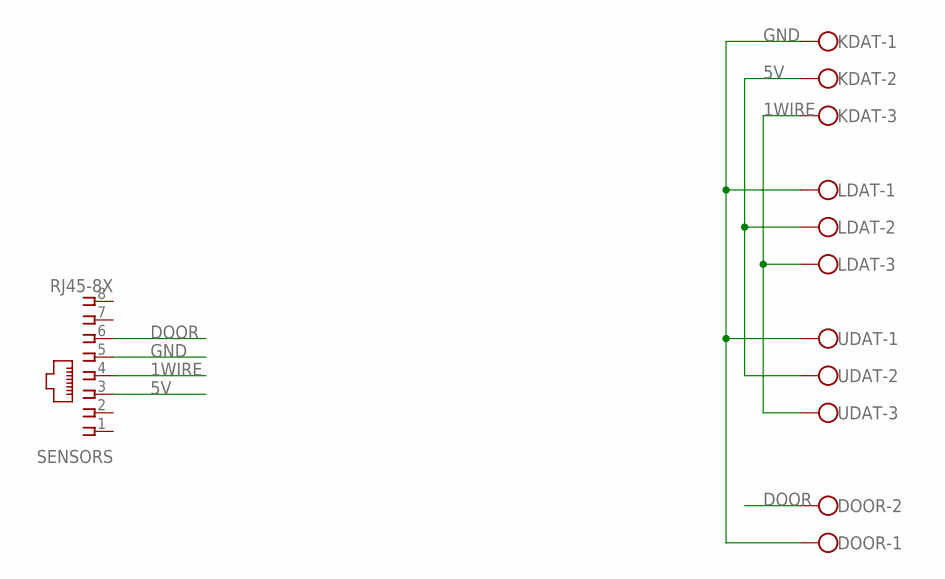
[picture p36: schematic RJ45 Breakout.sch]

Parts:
DOOR: W237-102
KDAT: W237-103
LDAT: W237-103
SENSORS: RJ45-8X; RJ45-NO-SHIELD
UDAT: W237-103

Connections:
1WIRE: KDAT.3, LDAT.3, SENSORS.4, UDAT.3
5V: KDAT.2, LDAT.2, SENSORS.3, UDAT.2
DOOR: DOOR.2, SENSORS.6
GND: DOOR.1, KDAT.1, LDAT.1, SENSORS.5, UDAT.1

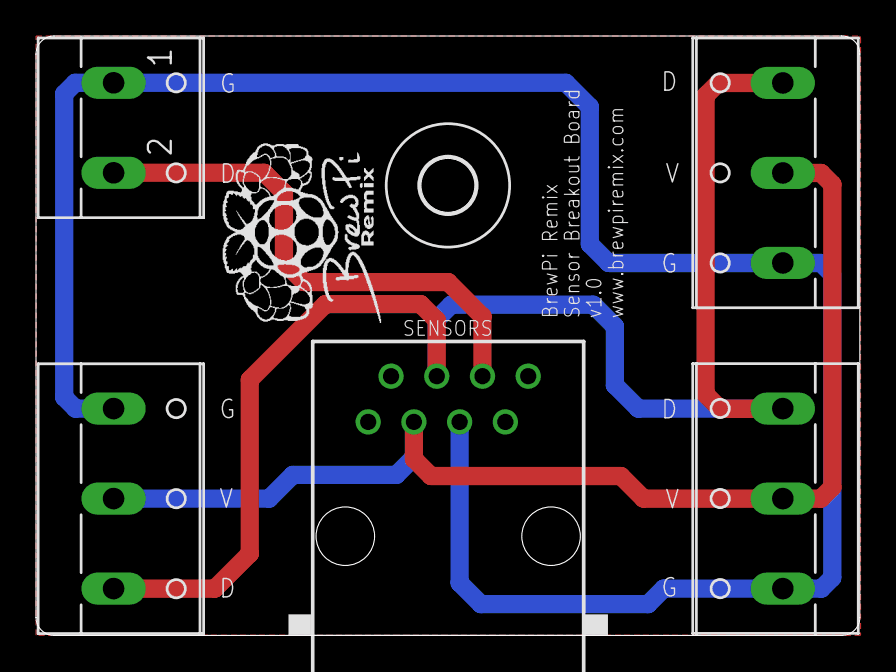
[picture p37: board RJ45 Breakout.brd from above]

Board: 2 copper layers, 45.8 x 33.3 mm, 6 parts (0 on the bottom side), 4 nets.

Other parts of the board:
U$1: 3,0

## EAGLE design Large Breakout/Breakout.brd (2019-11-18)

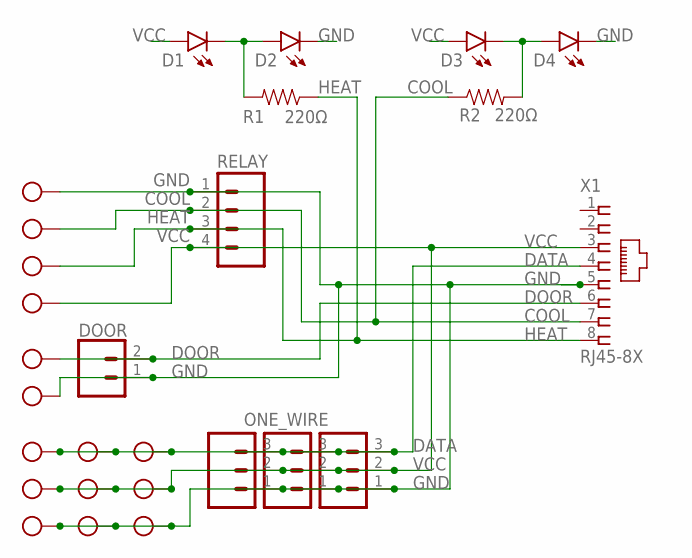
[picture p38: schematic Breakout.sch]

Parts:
D1: HINV; LED_3MM
D2: HNON; LED_3MM
D3: CINV; LED_3MM
D4: CNON; LED_3MM
DOOR: 2-PIN; 1X02
ONE_WIRE1, ONE_WIRE2, ONE_WIRE3: 3-PIN; 1X03
R1, R2: 220Ω; AXIAL-0.3
RELAY: 4-PIN; 1X04
RELAY_TERM: 4TERM; W237-4
X1: RJ45-8X; RJ45-NO-SHIELD
X2: 4TERM; W237-102
X3, X4, X5: 3TERM; W237-103

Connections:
COOL: R2.P$1 (1), RELAY.2, RELAY_TERM.2, X1.7
DATA: ONE_WIRE1.3, ONE_WIRE2.3, ONE_WIRE3.3, X1.4, X3.1, X4.1, X5.1
DOOR: DOOR.2, X1.6, X2.1
GND: D2.K (C), D4.K (C), DOOR.1, ONE_WIRE1.1, ONE_WIRE2.1, ONE_WIRE3.1, RELAY.1, RELAY_TERM.1, X1.5, X2.2, X3.3, X4.3, X5.3
HEAT: R1.P$1 (1), RELAY.3, RELAY_TERM.3, X1.8
unnamed: D1.K (C), D2.A, R1.P$2 (2)
unnamed: D3.K (C), D4.A, R2.P$2 (2)
VCC: D1.A, D3.A, ONE_WIRE1.2, ONE_WIRE2.2, ONE_WIRE3.2, RELAY.4, RELAY_TERM.4, X1.3, X3.2, X4.2, X5.2

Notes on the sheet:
ONE_WIRE

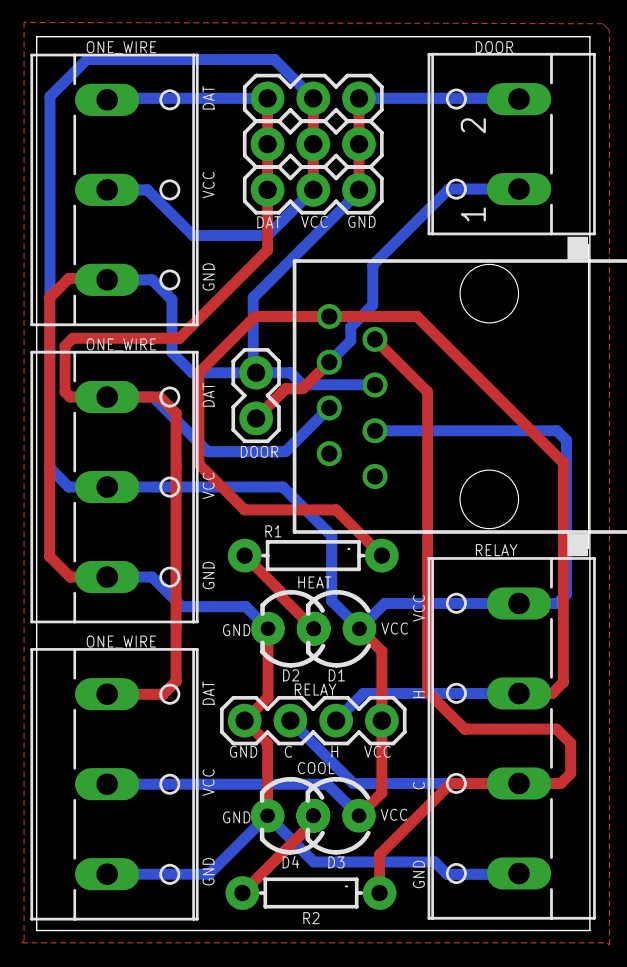
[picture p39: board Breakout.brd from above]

Board: 2 copper layers, 30.7 x 49.7 mm, 17 parts (0 on the bottom side), 8 nets.

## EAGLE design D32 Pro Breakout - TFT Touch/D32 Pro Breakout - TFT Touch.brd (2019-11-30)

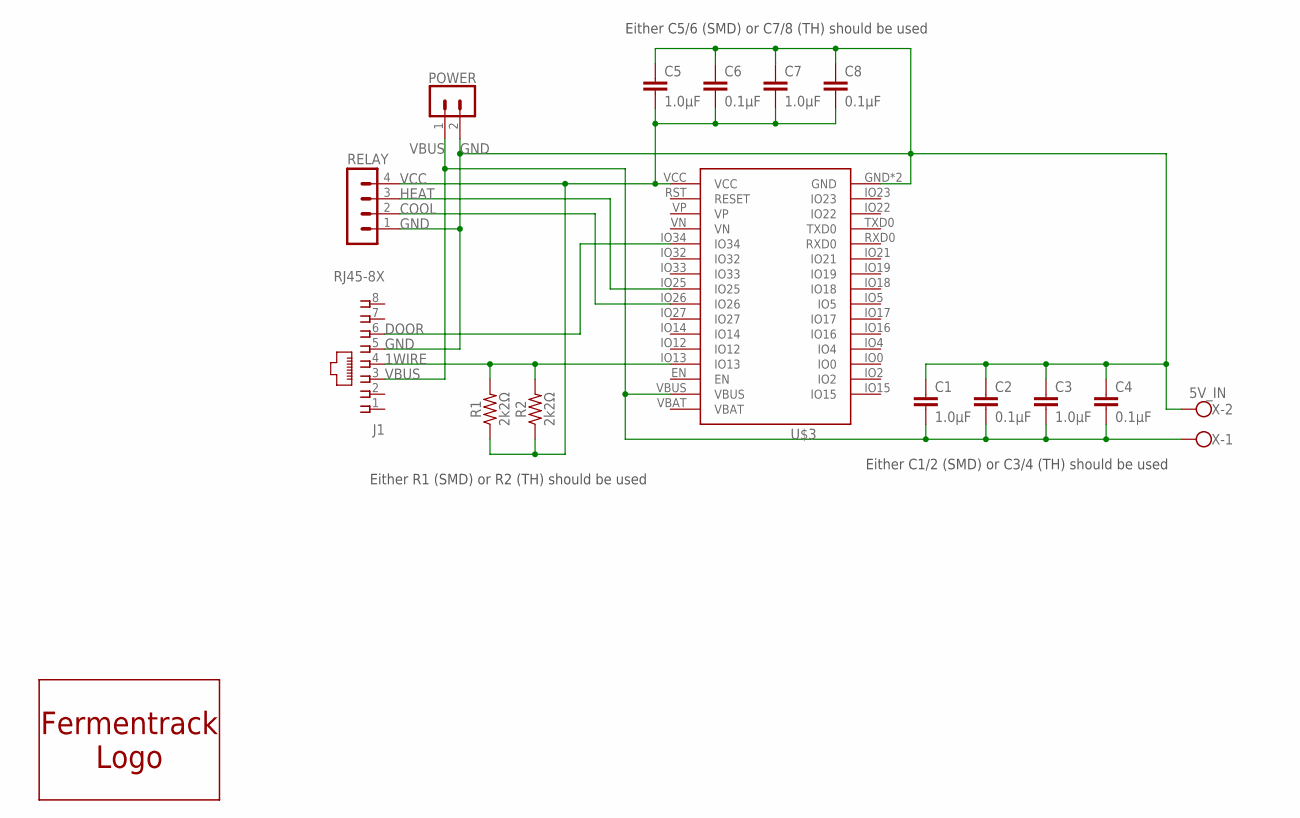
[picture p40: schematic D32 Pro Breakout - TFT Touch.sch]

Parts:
C1, C5: 1.0μF; SMD-1206
C2, C6: 0.1μF; SMD-1206
C3, C7: 1.0μF; CAP_PTH-2.54
C4, C8: 0.1μF; CAP_PTH-2.54
J1: RJ45-8X; RJ45-NO-SHIELD-NOLINE
R1: 2k2Ω; SMD-1206
R2: 2k2Ω; AXIAL-0.3
RELAY: HDR-4_VERT
U$3: WEMOS-D32D32_PRO_NO-BATT; D32_PRO_NO-BATT
U$5: POWER; HDR-2_VERT
U$6: LOGO_FERMENTRACKFERMENTRACK-LOGO_HALFINCH; FERMENTRACK-LOGO_SM
X: 5V_IN; W237-102

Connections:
1WIRE: J1.4, R1.2, R2.P$2 (2), U$3.IO13
COOL: RELAY.2, U$3.IO26
DOOR: J1.6, U$3.IO34
GND: C1.1, C2.1, C3.1, C4.1, C5.1, C6.1, C7.1, C8.1, J1.5, RELAY.1, U$3.GND, U$3.GND2 (GND), U$5.2, X.2
HEAT: RELAY.3, U$3.IO25
VBUS: C1.2, C2.2, C3.2, C4.2, J1.3, U$3.VBUS, U$5.1, X.1
VCC: C5.2, C6.2, C7.2, C8.2, R1.1, R2.P$1 (1), RELAY.4, U$3.VCC

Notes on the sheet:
Either C5/6 (SMD) or C7/8 (TH) should be used
Either R1 (SMD) or R2 (TH) should be used
Either C1/2 (SMD) or C3/4 (TH) should be used

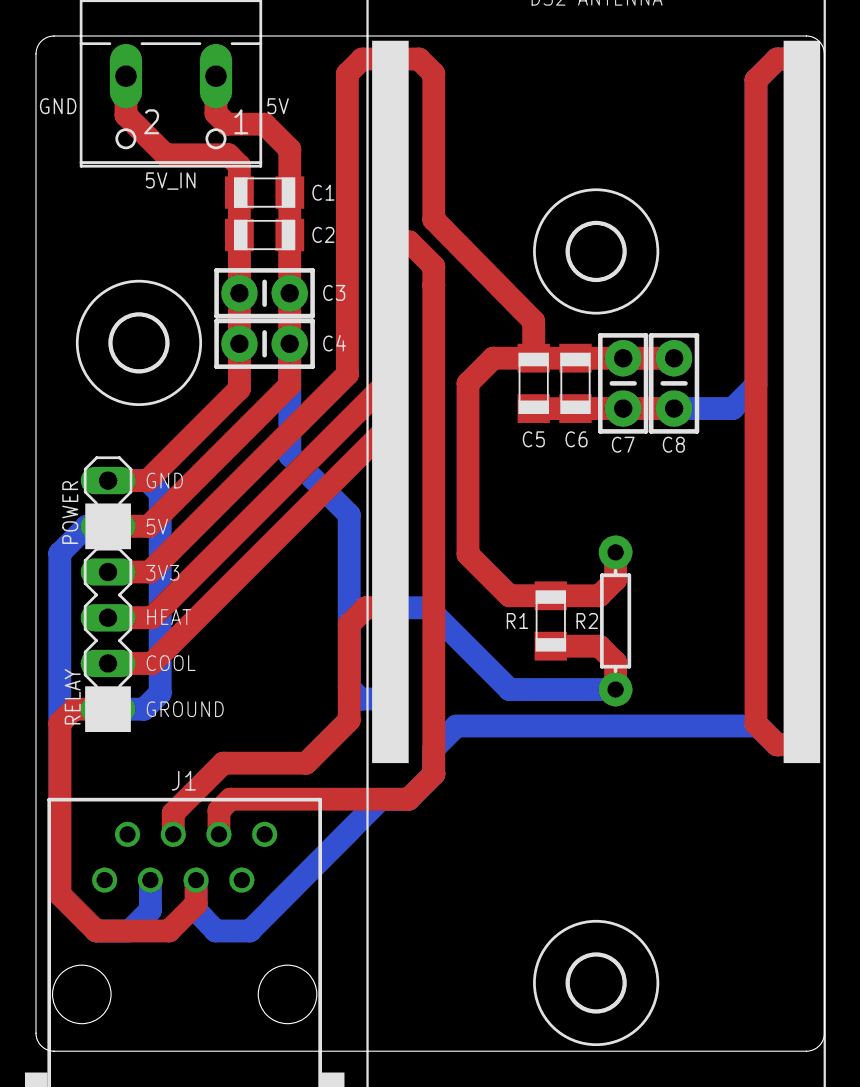
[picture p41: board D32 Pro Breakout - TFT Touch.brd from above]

Board: 2 copper layers, 43.8 x 56.4 mm, 19 parts (1 on the bottom side), 7 nets.

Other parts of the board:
U$1, U$2, U$4: 3,0

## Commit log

2019-06-23 Legacy 1.1 boards
    [BrewPi Shield v1.1 BOM Parts.csv, BrewPi Shield v1.1 BOM Values.csv, BrewPi Shield v1.1.brd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]
2019-06-23 Rename to versionless names
    [BrewPi Shield BOM Parts.csv, BrewPi Shield BOM Values.csv, BrewPi Shield.brd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]
2019-06-23 Rename shield directory
    [BrewPi Shield BOM Parts.csv, BrewPi Shield BOM Values.csv, BrewPi Shield.brd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]
2019-06-23 Version 1.2 upload
    [BrewPi Shield BOM Parts.csv, BrewPi Shield BOM Values.csv, BrewPi Shield.brd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]
2019-06-23 Initial upload
    [Breakout Parts.csv, Breakout Values.csv, Breakout.brd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]
2019-06-23 Version 1.3 upload
    [BrewPi Shield BOM Parts.csv, BrewPi Shield BOM Values.csv, BrewPi Shield.brd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]
2019-06-23 Version 1.3.1 upload
    [BrewPi Shield BOM Parts.csv, BrewPi Shield BOM Values.csv, BrewPi Shield.brd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]
2019-06-23 Moved traces and silkscreens
    [BrewPi Shield.brd, BrewPi Shield.sch]
2019-06-30 Update logo
    [BrewPi Shield.brd]
2019-06-30 Update logo, remove acid trap
    [RotEncoder.brd]
2019-06-30 Add labels for LEDs
    [Breakout.brd]
2019-11-10 Add ESP8266 shield
    [BOM Parts - D1 - TH LCD Dupont RJ45.csv, BOM Values - D1 - TH LCD Dupont RJ45.csv, D1 - TH LCD Dupont RJ45.brd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]
2019-11-18 Remove 90deg connection at power
    [D1 - TH LCD Dupont RJ45.brd]
2019-11-18 Change to pcbs.io link
2019-11-18 Update to pcbs.io images
2019-11-18 Change all links to pcbs.io
2019-11-18 Remove a bunch of 90's
    [Breakout.brd]
2019-11-18 Update pours
    [D1 - TH LCD Dupont RJ45.brd, RotEncoder.brd]
2019-11-30 New board for D32 Pro
    [D32 Pro Breakout - TFT Touch.brd, D32 Pro Breakout - TFT Touch.sch]
2019-11-30 Update D1, rename dirs
    [BOM Parts - D1 - TH LCD Dupont RJ45.csv, BOM Values - D1 - TH LCD Dupont RJ45.csv, Breakout Parts.csv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]
2019-11-30 Add RJ45 Sensor Breakout
    [RJ-45 Sensor Breakout.brd, RJ-45 Sensor Breakout.sch]
2019-11-30 Add BOMs
    [BOM Parts RJ-45 Sensor Breakout.csv, BOM Values RJ-45 Sensor Breakout.csv, RJ-45 Sensor Breakout.brd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]
2019-12-01 Rename, add GND to mounting ears
    [RotEncoder.sch, Rotary Encoder Breakout.brd, Rotary Encoder Breakout.sch]
2019-12-01 Add grounds to the shield
    [Rotary Encoder Breakout.brd]
2019-12-01 Updated part
    [RotEncoder Parts.csv, RotEncoder Values.csv, Rotary Encoder Breakout.brd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]
2019-12-02 Update README's images and links
    [D1 - TH LCD Dupont RJ45.brd, RJ-45 Sensor Breakout.brd]
2020-05-22 Silk for pins was reversed
    [D1 - TH LCD Dupont RJ45.brd]
2020-05-22 Rename folders
    [BOM Parts - D1 - TH LCD Dupont RJ45.csv, BOM Parts RJ-45 Sensor Breakout.csv, BOM Values - D1 - TH LCD Dupont RJ45.csv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]
2020-11-09 Add RJ45 Breakout
    [BOM Parts RJ-45 Sensor Breakout.csv, BOM Values RJ-45 Sensor Breakout.csv, BrewPi Shield.brd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]
2021-03-15 Reorganize and add I2C shield
    [BrewPi Combo Shield.brd, BrewPi Combo Shield.sch, BrewPi LCD Shield.brd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]
2021-03-15 Add voltage select header
    [BrewPi Combo Shield.brd, D1 - TH LCD Dupont RJ45.brd, D1 - TH LCD Dupont RJ45.sch]
2021-03-16 Fix pour and links
    [BOM Parts - D1 - TH LCD Dupont RJ45.csv, BOM Values - D1 - TH LCD Dupont RJ45.csv, D1 - TH LCD Dupont RJ45.brd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]
2024-10-19 Add schematic
2024-10-19 Add more info for I2C shield variant
2024-10-19 Remove PCB.io link

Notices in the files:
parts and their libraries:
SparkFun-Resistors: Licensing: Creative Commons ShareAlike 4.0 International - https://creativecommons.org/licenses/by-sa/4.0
